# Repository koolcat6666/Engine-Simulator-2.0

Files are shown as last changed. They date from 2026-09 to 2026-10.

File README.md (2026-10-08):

# Engine Simulator 2.0

Engine simulator for ECU testing based on the Speeduino V0.4 and the ESP32-32U DevKitC.

The system connects to the ECU through the standard Speeduino 40-pin IDC connector and generates signals to simulate real engine operation.

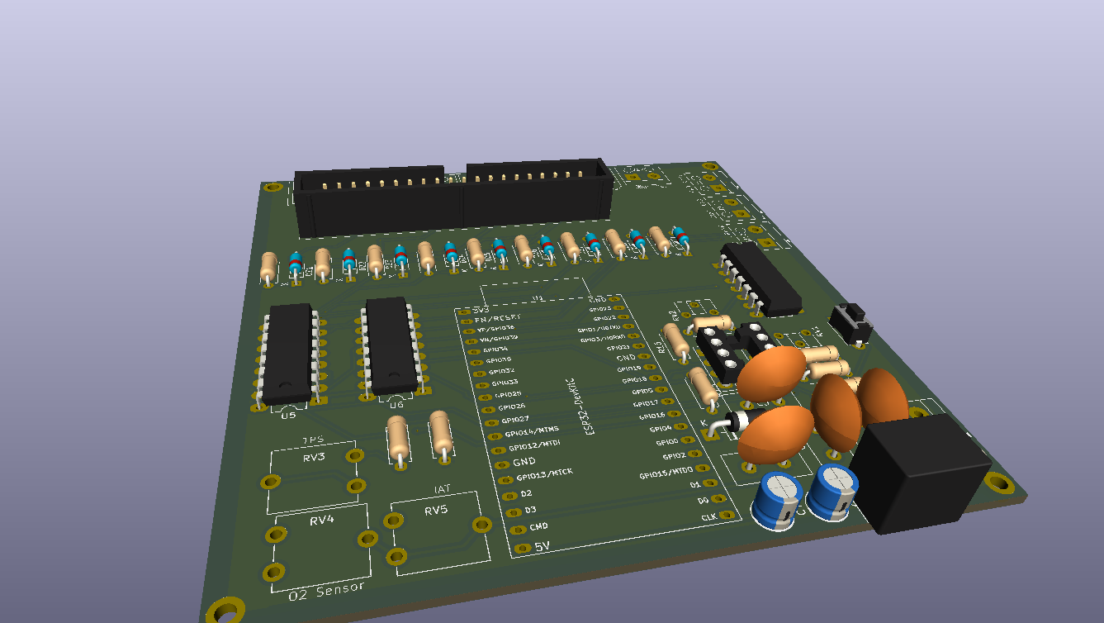
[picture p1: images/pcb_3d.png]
PCB 3D render


## Architecture

### Signals generated by the ESP32

| Signal | ESP32 Pin | To Speeduino | Method |
|:---|:---:|:---:|:---|
| Crank Trigger | GPIO 12 | IDC Pin 25 | Square wave via hardware timer and 3.3V-to-5V level shifter |
| Cam 1 Trigger | GPIO 13 | IDC Pin 24 | Square wave via hardware timer and 3.3V-to-5V level shifter |
| Cam 2 Trigger | GPIO 14 | IDC Pin 24 (optional) | Square wave via hardware timer and 3.3V-to-5V level shifter |
| CLT (Coolant Temperature) | GPIO 26 (DAC2) | IDC Pin 19 | Analog voltage 0–3.3V, amplified to 0–5V |
| MAP (Pressure) | GPIO 25 (DAC1) | IDC Pin 11 | Analog voltage 0–3.3V, amplified to 0–5V |

### Manually controlled signals (potentiometers)

| Signal | Speeduino Pin | Notes |
|:---|:---:|:---|
| TPS (Throttle Position Sensor) | IDC Pin 22 | 5V potentiometer, wiper/common connected to ESP32 ADC (GPIO 34) through a voltage divider |
| IAT (Intake Air Temperature) | IDC Pin 20 | Potentiometer connected directly to Speeduino |
| O2 (Oxygen Sensor) | IDC Pin 21 | Potentiometer connected directly to Speeduino |

### ECU input signals

| Signal | ESP32 Pin | From Speeduino | Notes |
|:---|:---:|:---:|:---|
| Fan Feedback | GPIO 27 | IDC Pin 15 | Fan status (0V = ON), 5V-to-3.3V voltage divider |

### ECU outputs monitoring

Speeduino outputs such as injectors, ignition/coils, fan, idle, VVT, boost, and fuel pump are read by the ESP32 through CD4050BE buffers for timing calculation (Phase 2).

---

## Firmware features

- 64 trigger wheel / crank patterns (ArduStim compatible): 60-2, 36-1, 24-1, LS1, 58X, Chrysler NGC, BMW N20, GM 40-tooth OSS, and many others
- RPM inertia model: cranking from 0 to 350 RPM, then idle at 850 RPM + (TPS × 6150), with low-pass filtering
- Start/Stop button: starts and stops the engine with a cranking ramp, idle stabilization, and gradual shutdown
- Dynamic MAP simulation: 100 kPa with engine off, 85 kPa during cranking, and 30–100 kPa depending on RPM and TPS
- Dynamic CLT simulation: gradual warm-up, fan cooling, and Newton cooling when engine is off
- USB serial interface: ArduStim protocol for configuring trigger wheel and crank pattern, as well as RPM mode from TunerStudio
- Speeduino timing monitoring (Phase 2): input capture via ISR on 9 CD4050BE inputs (4 injectors + 4 coils + fan), measuring injector on-time, pulse frequency, duty cycle, ignition dwell and advance
- WiFi AP + web dashboard (Phase 3): SSID `EngineSimulator2.0`, password `1234567890`, IP `192.168.254.1`, responsive dashboard at `/`, allows selecting one of 64 trigger patterns and persists the setting to NVS memory

### Verification status

| Module | Status |
|:---|:---|
| Phase 1 — Crank/Cam generation and engine model | Verified on hardware (Speeduino / Mega2560 reads engine speed correctly; fixed GPIO register usage `GPIO.out_w1ts/w1tc` in the ISR for core v3.3.x) |
| Phase 2 — Injector/ignition timing (input capture) | Implemented and compiled successfully — hardware validation pending |
| Phase 3 — WiFi AP + web dashboard | Implemented and compiled successfully — hardware validation pending |

Details and references: `firmware/WORKING_VERSION.md`.

---

## Directory structure

```
Engine Simulator 2.0/
||| firmware/                    # ESP32 source code
|   ||| Engine_Simulator_2.0.ino # Main sketch (timer, simulation, state machine)
|   ||| comms.cpp                # Serial command parser (ArduStim protocol)
|   ||| comms.h                  # Comms header
|   ||| globals.h                # Shared data structures
|   ||| timing.cpp               # Input capture timing for injectors/ignition (Phase 2)
|   ||| timing.h                 # Timing header
|   ||| web.cpp                  # WiFi AP + dashboard + /setup + /api/data (Phase 3)
|   ||| web.h                    # Web header
|   ||| wheel_defs.h             # 63 trigger wheel definitions
||| Engine_Simulator_2_0/        # Arduino IDE copy (folder name matches .ino project)
||| Hardware/                    # PCB design (KiCad 10.0)
|   ||| Engine Simulator 2.0/
|       ||| *.kicad_sch          # Schematic
|       ||| *.kicad_pcb          # PCB layout
|       ||| *.kicad_pro          # KiCad project
|       ||| BOM.md               # Bill of materials (updated from netlist)
|       ||| Gerbers/             # Manufacturing files (Gerber + drill)
||| doc/                         # Documentation
|   ||| dupont_pinout.md         # Speeduino V0.4 40-pin IDC pinout
|   ||| esp32u_pin_assignment.md # ESP32U pin mapping
||| README.md                    # This file
```

---

## Hardware requirements

### Main components

| Component | Quantity | Description |
|:---|:---:|:---|
| ESP32-WROOM-32U | 1 | Main microcontroller |
| 74AHCT125 | 1 | Quadruple level shifter 3.3V -> 5V (Crank, Cam1, Cam2) |
| TLV2372 | 1 | Dual rail-to-rail op-amp (MAP/CLT buffers) |
| R-78E5.0-1.0 (RECOM) | 1 | Switching regulator drop-in 12V -> 5V, 1A, 91% efficiency |
| 40-pin IDC connector | 1 | Connection to Speeduino V0.4 |
| CD4050BE | 2 | Hex buffer for ECU inputs (injectors, ignition, fan) |
| Trimmer potentiometers | 5 | (2 kΩ x2, 10 kΩ x3) — TPS, IAT, O2, and others |
| Push button | 1 | Start/Stop |
| DC barrel jack | 1 | 12V power input |

### Voltage levels

| Section | Voltage | Method |
|:---|:---:|:---|
| Board power supply | 12V | External DC barrel jack |
| Logic supply | 5V | R-78E5.0-1.0 switching regulator from 12V |
| ESP32 and sensors | 3.3V | Onboard regulator |
| ESP32 digital outputs -> ECU | 3.3V -> 5V | 74AHCT125 |
| ESP32 analog outputs -> ECU | 0–3.3V -> 0–5V | TLV2372 (gain 1.5x) |
| Fan input from ECU | 5V -> 3.3V | Resistive divider |

---

## Build and upload

### Prerequisites

- [Arduino IDE](https://www.arduino.cc/en/software) or [Arduino CLI](https://arduino.github.io/arduino-cli/)
- ESP32 board package installed: `esp32:esp32` via Board Manager
- Selected board: `ESP32 Dev Module` or `ESP32-WROOM-32U`
- Libraries for the dashboard (Phase 3): use **ESP32Async** (compatible with ESP32 core v3.3.x and mbedTLS 3; the classic `me-no-dev` version does not compile)
  - **ESP Async WebServer** (`arduino-cli lib install "ESP Async WebServer"`)
  - **Async TCP** (`arduino-cli lib install "Async TCP"`)

### Compile and upload

```bash
# Via Arduino CLI (first time: install the dashboard libraries as well)
arduino-cli lib install "ESP Async WebServer" "Async TCP"
arduino-cli compile --fqbn esp32:esp32:esp32 firmware/Engine_Simulator_2.0.ino
arduino-cli upload --fqbn esp32:esp32:esp32 --port COMx firmware/Engine_Simulator_2.0.ino
```

### Configuration

The trigger wheel/crank pattern can be selected in the following ways:

1. Dashboard web interface (recommended): connect to WiFi `EngineSimulator2.0` (password `1234567890`) and open `http://192.168.254.1` -> page `/setup` to select the pattern (persisted to NVS memory)
2. USB serial (115200 baud): use command `X` to select the next pattern, or `S<n>` to select by index
3. ArduStim GUI: desktop software connecting via serial to configure patterns and modes

---

## Project notes

- The integrated MAP sensor on the Speeduino V0.4 (IDC Pin 11) cannot be used as an alternative to the DAC-generated signal from the ESP32 for simulation. In this case, the MAP pin of the IDC must be disconnected and re-routed to the proper simulation output.
- The fan is managed with feedback: Speeduino controls it, and the ESP32 reads it to model CLT temperature.
- The IAT and O2 potentiometers are purely manual and do not affect the ESP32 simulation. They are used to test ECU corrections.
- The KiCad PCB (`Hardware/Engine Simulator 2.0/`) is complete: 2-layer routing with a solid GND plane on the bottom copper layer and thermal reliefs. DRC: no clearance errors and no unconnected pads; only cosmetic warnings remain.
- The design is intended to be a compact, low-cost and fully functional engine simulation interface for ECU testing and development.

### Manufacturing outputs (Gerber + drill)

Manufacturing files are generated with `kicad-cli` and are ready for any fabrication house (JLCPCB, PCBWay, PCBcart):

- `Hardware/Engine Simulator 2.0/Gerbers/` — Gerber RS-274X, 9 layers (`F_Cu`, `B_Cu`, `F_Paste`, `B_Paste`, `F_Mask`, `B_Mask`, `F_SilkS`, `B_SilkS`, `Edge_Cuts`) + `.gbrjob` file
- `Hardware/Engine Simulator 2.0/Gerbers/` — Separate Excellon drill files: `-PTH.drl` (plated holes, 0.3–2.2 mm) and `-NPTH.drl` (non-plated holes)
- `Hardware/Engine Simulator 2.0/Engine_Simulator_2.0_FAB_gerbers.zip` — ZIP archive containing all Gerber and drill files, ready for direct upload to the manufacturer

Board: 2 layers, 100 × 100 mm, thickness 1.6 mm, HASL finish, minimum trace width 0.2 mm, minimum clearance 0.21 mm, minimum drill 0.3 mm (via) / 2.2 mm (M2 mounting holes, PTH connected to GND).

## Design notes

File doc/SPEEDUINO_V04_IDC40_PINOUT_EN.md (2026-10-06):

# Speeduino V0.4 - IDC 40-Pin Connector Pinout

Pinout ufficiale del connettore IDC 40 pin della **Speeduino V0.4**.  
Riferimento: [Speeduino Wiki - V04 Board](https://wiki.speeduino.com/en/boards/V04)

## IDC 40-Pin Pinout Table (Speeduino V0.4)

| Pin IDC | Funzione |
|:---:|:---|
| 1 | Injector 1 - Pin 1/2 |
| 2 | Injector 2 - Pin 1/2 |
| 3 | Injector 3 - Pin 1/2 |
| 4 | Injector 3 - Pin 2/2 |
| 5 | Injector 4 - Pin 1/2 |
| 6 | Injector 4 - Pin 2/2 |
| 7 | Ignition 1 |
| 8 | Ignition 4 |
| 9 | Ground (Sensori) |
| 10 | Ground |
| 11 | MAP Sensor (0-5V) |
| 12 | Ground |
| 13 | +5V |
| 14 | Proto Area 1 (v0.4.4b+: Flex Sensor) |
| 15 | Proto Area 2 (v0.4.4b+: Fan) |
| 16 | Proto Area 3 (v0.4.4b+: Fuel Pump) |
| 17 | Proto Area 4 (v0.4.4b+: Tachometer) |
| 18 | Proto Area 5 (v0.4.4b+: Clutch) |
| 19 | CLT (Coolant Temperature) |
| 20 | IAT (Inlet Air Temperature) |
| 21 | O2 Sensor |
| 22 | TPS (Throttle Position Sensor) |
| 23 | Ground |
| 24 | Cam Input / VR2+ |
| 25 | Crank Input / VR1+ |
| 26 | VR2- (non usato per sensori Hall) |
| 27 | VR1- (non usato per sensori Hall) |
| 28 | +5V |
| 29 | Stepper Motor 2B |
| 30 | Stepper Motor 2A |
| 31 | Stepper Motor 1A |
| 32 | Stepper Motor 1B |
| 33 | Ignition 3 |
| 34 | Ignition 2 |
| 35 | Boost Control |
| 36 | Idle 2 (3-wire idle valve) |
| 37 | PWM Idle (1-wire idle) |
| 38 | VVT |
| 39 | Injector 2 - Pin 2/2 |
| 40 | Injector 1 - Pin 2/2 |

---

## Default Output Functions (v0.4.4b+)

| Funzione | Pin IDC | Arduino Pin | Note |
|:---|:---:|:---:|:-----|
| Boost Control | 35 | 7 | Disabilitare in TunerStudio e rimappare a Pin 4 |
| VVT | 38 | 4 | Disabilitare in TunerStudio |
| Idle 1 (PWM) | 37 | 5 | |
| Idle 2 (3-wire) | 36 | 6 | |
| Fuel Pump | 16 | 45 | Jumper da proto area |
| Fan | 15 | 47 | Jumper da proto area |
| Tachometer | 17 | 49 | Jumper da proto area |
| Launch/Clutch | 18 | 51 | Jumper da proto area |

---

## Sensori di Input (Pezzo 0.4)

| Funzione | Arduino Pin | Descrizione |
|:---|:---:|:---|
| Crank Trigger | 19 | Sensore CKP (VR o Hall) |
| Cam Trigger | 18 | Sensore CMP (VR o Hall) |
| Cam 2 / VVT2 | 3 | Secondo sensore fase |
| TPS | A2 | Throttle Position Sensor |
| MAP | A3 | MAP Sensor (integrato sulla board) |
| IAT | A0 | Intake Air Temperature |
| CLT | A1 | Coolant Temperature |
| O2 | A8 | Sonda Lambda |
| Battery | A4 | Riferimento tensione batteria |

---

## Collegamenti verso Engine Simulator 2.0 (ESP32)

Di seguito la mappatura dei pin IDC collegati all'ESP32 sul PCB del simulatore:

| Pin IDC | Funzione Speeduino | Direzione (per ECU) | Collegamento ESP32 | Note Hardware |
|:---:|:---:|:---:|:---:|:---|
| 11 | MAP | **Ingresso ECU** | DAC1 (GPIO 25) via op-amp | Generato da ESP32 (0-3.3V amplificato a 0-5V) |
| 19 | CLT | **Ingresso ECU** | DAC2 (GPIO 26) via op-amp | Generato da ESP32 (0-3.3V amplificato a 0-5V) |
| 20 | IAT | **Ingresso ECU** | Potenziometro manuale | Regolatore esterno, collegato direttamente a Speeduino |
| 22 | TPS | **Ingresso ECU** | Potenziometro con partitore | Regolatore esterno, collegato a Speeduino + partitore verso ESP32 ADC (GPIO 34) |
| 21 | O2 | **Ingresso ECU** | Potenziometro manuale | Regolatore esterno, collegato direttamente a Speeduino |
| 25 | Crank | **Uscita ECU** (input per Speeduino) | GPIO 12 via level shifter 3.3V->5V | Segnale generato da ESP32 |
| 24 | Cam | **Uscita ECU** (input per Speeduino) | GPIO 13 via level shifter 3.3V->5V | Segnale generato da ESP32 |
| 15 | Fan | **Uscita ECU** | CD4050-A out 6 -> GPIO 27 | Lettura stato ventola (temperatura CLT) |
| 1 | Injector 1 | **Uscita ECU** | CD4050-B out 4 -> GPIO 15 | Input capture timing (FASE 2) |
| 2 | Injector 2 | **Uscita ECU** | CD4050-B out 6 -> GPIO 16 | Input capture timing (FASE 2) |
| 3 | Injector 3 | **Uscita ECU** | CD4050-B out 10 -> GPIO 17 | Input capture timing (FASE 2) |
| 5 | Injector 4 | **Uscita ECU** | CD4050-B out 12 -> GPIO 18 | Input capture timing (FASE 2) |
| 7 | Ignition 1 | **Uscita ECU** | CD4050-A out 10 -> GPIO 19 | Input capture timing (FASE 2) |
| 8 | Ignition 4 | **Uscita ECU** | CD4050-A out 2 -> GPIO 23 | Input capture timing (FASE 2) |
| 33 | Ignition 3 | **Uscita ECU** | CD4050-A out 15 -> GPIO 22 | Input capture timing (FASE 2) |
| 34 | Ignition 2 | **Uscita ECU** | CD4050-A out 12 -> GPIO 21 | Input capture timing (FASE 2) |
| 37 | Idle (PWM) | **Uscita ECU** | Non monitorata | (Monitorabile in futuro) |
| 35 | Boost | **Uscita ECU** | Non monitorata | (Monitorabile in futuro) |
| 38 | VVT | **Uscita ECU** | Non monitorata | (Monitorabile in futuro) |
| 16 | Fuel Pump | **Uscita ECU** | Non monitorata | (Monitorabile in futuro) |

---

## Note sui Livelli di Tensione

### Uscite ESP32 -> Speeduino (3.3V -> 5V)
I segnali digitali generati dall'ESP32 (Crank, Cam1) sono a logica 3.3V. Devono essere traslati a 5V tramite **74AHCT125** (level shifter) prima di essere inviati ai pin Crank/Cam dell'IDC.

### Uscite Analogiche ESP32 -> Speeduino
I DAC dell'ESP32 (GPIO 25, 26) erogano 0-3.3V. Vanno amplificati a 0-5V tramite **op-amp rail-to-rail** (TLV2372) con guadagno ~1.5x per compatibilita' con gli ingressi analogici di Speeduino (MAP e CLT).

### Ingressi da Speeduino -> ESP32 (5V -> 3.3V)
Il segnale Fan (pin 15 IDC) e' a 5V. Deve essere ridotto a 3.3V tramite partitore resistivo prima di essere letto dal GPIO 27 dell'ESP32.

### Potenziometri TPS/IAT/O2
I potenziometri sono alimentati a 5V (condiviso con Speeduino). Il cursore va collegato:
- **TPS**: a Speeduino (pin 22 IDC) + partitore resistivo 10k/20k verso GPIO 34 ESP32
- **IAT**: direttamente a Speeduino (pin 20 IDC), nessun collegamento ESP32
- **O2**: direttamente a Speeduino (pin 21 IDC), nessun collegamento ESP32

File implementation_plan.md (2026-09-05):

# Engine Simulator 2.0 - Implementation Plan

Il progetto **Engine Simulator 2.0** ha lo scopo di creare un simulatore ECU basato su ESP32, compatibile a livello seriale con ArduStim, ma arricchito con la simulazione fisica dei parametri motore (MAP, CLT, inerzia RPM basata su TPS, sequenza di cranking con pulsante di Start/Stop) e un'interfaccia hardware (PCB) per connettersi direttamente a Speeduino tramite un connettore Dupont a 40 pin.

---

## User Review Required

> [!IMPORTANT]
> **Compatibilità di Tensione e Level Shifting:**
> - ESP32 lavora a **3.3V** sia per gli ingressi analogici (ADC max 3.3V) che per i GPIO.
> - Speeduino lavora a **5V**.
> - I potenziometri (TPS, IAT, CLT, O2) saranno alimentati a 5V per Speeduino. Per far leggere il TPS anche a ESP32 senza bruciare l'ADC, si utilizzerà un partitore resistivo o un buffer sul PCB.
> - Le uscite dell'ESP32 (Crank, Cam, Cam2) devono passare attraverso un level shifter a 5V prima di raggiungere Speeduino.
> - Gli ingressi di Speeduino letti da ESP32 (es. comando Ventola di raffreddamento a 5V) passeranno attraverso un level shifter a 3.3V.

> [!TIP]
> **Generazione Analogica (CLT e MAP):**
> L'ESP32 ha 2 canali DAC integrati a 8 bit (GPIO25 e GPIO26). Li useremo per generare le tensioni analogiche di MAP e CLT (che andranno poi traslate a 0-5V tramite op-amp sul PCB se Speeduino richiede range 0-5V, dato che i DAC di ESP32 erogano 0-3.3V).

---

## Proposed Changes

Creeremo la cartella `C:\Users\nicola\Desktop\Engine Simulator 2.0` con la seguente struttura di file:

### Componente 1: Firmware ESP32
Adatteremo la logica di generazione delle ruote foniche di ArduStim per usare i timer hardware di ESP32 (tramite le API ESP32 Arduino Core `esp32-hal-timer.h`), implementando al contempo le routine di simulazione fisica in background.

#### [NEW] [Engine_Simulator_2.0.ino](file:///C:/Users/nicola/Desktop/Engine%20Simulator%202.0/firmware/Engine_Simulator_2.0.ino)
Contiene il punto di ingresso dell'applicazione, la configurazione dei timer hardware di ESP32 per la ruota fonica e il loop principale che gestisce:
- Lettura pulsante Start/Stop (con debouncing e macchina a stati del motore: `SPENTO`, `CRAKING`, `ACCESO`, `SPEGNIMENTO`).
- Lettura TPS (ADC ESP32) e calcolo dinamico degli RPM correnti applicando le leggi di inerzia (accelerazione e decelerazione simulate).
- Calcolo e aggiornamento dell'uscita DAC per **MAP** (in base a RPM, TPS, tasso di variazione RPM).
- Calcolo e aggiornamento dell'uscita DAC per **CLT** (in base a tempo di accensione, RPM, stato della ventola letto dall'ECU).
- Gestione della comunicazione seriale (comandi ArduStim per cambiare ruota fonica o ricevere configurazioni).

> **[!IMPORTANT] Fix verificato su hardware (2026-09):** sulla ISR del timer `onCrankTimer()` l'uso di `digitalWrite()` NON aggiorna i pin GPIO su ESP32 Arduino Core v3.3.5 (i segnali Crank/Cam restavano a 0V anche a motore avviato). Risolto sostituendo `digitalWrite` con la **scrittura diretta ai registri GPIO** (`GPIO.out_w1ts` per HIGH, `GPIO.out_w1tc` per LOW), che funziona sempre dentro una ISR. Aggiunti gli include `soc/gpio_struct.h` e `soc/gpio_reg.h`. Dopo questa patch il segnale Crank/Cam commuta correttamente (tensione media ~1.6V = square 3.3V a duty ~50%) e Speeduino/Mega2560 legge i giri.

#### [NEW] [wheel_defs.h](file:///C:/Users/nicola/Desktop/Engine%20Simulator%202.0/firmware/wheel_defs.h)
Le definizioni delle ruote foniche importate da ArduStim (es. 60-2, 36-1, ecc.) adattate per ESP32.

#### [NEW] [comms.h](file:///C:/Users/nicola/Desktop/Engine%20Simulator%202.0/firmware/comms.h) & [comms.cpp](file:///C:/Users/nicola/Desktop/Engine%20Simulator%202.0/firmware/comms.cpp)
Modulo di comunicazione seriale compatibile con l'interfaccia ArduStim per consentire la selezione del pattern e configurazioni tramite PC.

---

### Componente 2: Documentazione Hardware & Repository
#### [NEW] [README.md](file:///C:/Users/nicola/Desktop/Engine%20Simulator%202.0/README.md)
Documentazione completa per GitHub, contenente:
- Descrizione del progetto.
- Schema a blocchi dell'hardware (Alimentazione 12V -> Regolatori 5V e 3.3V, Level Shifter, DAC 0-3.3V amplificati a 0-5V per MAP e CLT).
- Pinout del connettore Dupont a 40 pin per l'interfaccia con Speeduino.
- Guida all'uso e alla calibrazione.

#### [NEW] [dupont_pinout.md](file:///C:/Users/nicola/Desktop/Engine%20Simulator%202.0/doc/dupont_pinout.md)
Tabella dettagliata delle connessioni tra ESP32, Level Shifter e connettore Dupont a 40 pin di Speeduino.

---

## Logiche Fisiche Simulate

### 1. Inerzia RPM da TPS
- Quando il motore è acceso, il regime target è proporzionale all'apertura del TPS.
- Gli RPM effettivi seguono il target con un ritardo controllato da un coefficiente di inerzia (simulando la massa del volano):
  $$\text{RPM}_{\text{curr}} = \text{RPM}_{\text{curr}} + (\text{RPM}_{\text{target}} - \text{RPM}_{\text{curr}}) \times K_{\text{inerzia}}$$

### 2. Pressione Collettore (MAP)
- A motore spento: MAP = Pressione Atmosferica (~4.0V - 4.5V sul sensore a seconda del sensore MAP simulato).
- In Idle (TPS basso, RPM stabili): MAP cala drasticamente (forte vuoto, ~1.0V - 1.5V).
- In Accelerazione (TPS alto, RPM in salita): MAP sale rapidamente verso la pressione atmosferica (~4.0V) prima che gli RPM aumentino del tutto.
- In Decelerazione (TPS chiuso, RPM alti): MAP scende al minimo storico (~0.5V - 0.8V).

### 3. Temperatura Refrigerante (CLT)
- A motore spento da tempo: CLT = Temperatura Ambiente.
- A motore acceso: CLT sale gradualmente verso una temperatura di esercizio (~90°C). La velocità di riscaldamento dipende dagli RPM.
- Se CLT supera la soglia della ventola (~95°C), Speeduino attiva l'uscita Ventola. L'ESP32 rileva questo input e aumenta il coefficiente di raffreddamento, facendo calare o stabilizzare la temperatura.
- A motore spento: CLT scende lentamente verso la temperatura ambiente seguendo la legge del raffreddamento di Newton.

---

## FASE 2 - Level Shifter Ingressi + Monitoraggio Timing Iniettori/Candele

> [!NOTE]
> Questa sezione descrive l'implementazione pianificata. **Il monitoraggio PWM di iniettori/candele NON è ancora implementato** nel codice (gli 8-9 ingressi non sono ancora gestiti). Il firmware base (generazione Crank/Cam + modello motore) è invece funzionante e verificato su Speeduino.

### Obiettivo

Monitorare i segnali **PWM di uscita della Speeduino** (4 iniettori + 4 candele + ventola) per misurare i **tempi di apertura iniettori (ms) e l'anticipo candela (°)**. Questo consente di verificare in tempo reale che la ECU e le correzioni (lambda, CLT, ecc.) effettivamente modifichino i parametri.

### 1. Corsia dati: i segnali Speeduino da leggere (IDC 40 pin V0.4)

| # | Segnale | Pin IDC | Natura |
|:-:|:---|:---:|:---|
| 1 | Injector 1 | 1 | PWM low-side, attivo basso |
| 2 | Injector 2 | 2 | PWM low-side, attivo basso |
| 3 | Injector 3 | 3 | PWM low-side, attivo basso |
| 4 | Injector 4 | 5 | PWM low-side, attivo basso |
| 5 | Ignition 1 | 7 | PWM low-side, attivo basso |
| 6 | Ignition 2 | 34 | PWM low-side, attivo basso |
| 7 | Ignition 3 | 33 | PWM low-side, attivo basso |
| 8 | Ignition 4 | 8 | PWM low-side, attivo basso |
| 9 | Fan (retroazione ECU) | — | Segnale comando ventola, letto via CD4050-A |

Questi segnali sono a **5V/12V logica Speeduino**. Per leggerli con l'ESP32 (3.3V) serve una **rete di protezione + buffer** (CD4050BE) su ciascun ingresso.

### 2. Level Shifter: componente e necessita'

**Motivo:** Gli output iniettori/candele di Speeduino sono **low-side**: il pin IDC oscilla tra ~0V (ON) e fino a **12V** (batteria/Vdrive) quando OFF. Leggere direttamente questo pin supera i 3.3V dell'ESP32 e danneggerebbe sia il GPIO che qualsiasi level shifter a 5V (Vmax ~5.5V). Gli ESP32 DevKitC **non sono 5V/12V tolerant** → serve protezione dedicata.

**Componente scelto: 2x CD4050BE** (Hex Non-Inverting Buffer, 6 canali l'uno).

| Proprieta' | Valore |
|:---|:---|
| Tolleranza ingresso | **VDD max 18V** → sopporta i 12V Speeduino senza danno |
| Canali | 6 per chip (ne servono 8 ⇒ **2 chip**) |
| Alimentazione (decisione) | **VDD = 3.3V**, GND condiviso con ESP32 |
| Uscita | Livello VDD = **3.3V**, già compatibile direttamente con GPIO ESP32 |
| Direzione | Unidirezionale (ingresso → uscita), perfetto per la lettura |

**Cablaggio (2 chip CD4050BE, 1 chip per sistema):**

```
Speeduino IDC (iniettori/candele/ventola, 0-12V)
        |   (ogni segnale su un ingresso)
        ▼
  [ CD4050BE-A  = IGNITION  (4 candele: IGN1-4 + FAN) ]
  [ CD4050BE-B  = INJECTION (4 iniettori: INJ1-4)      ]
        |  (VDD=3.3V, GND=GND ESP32)
        ▼
  GPIO ESP32 (9 ingressi, livello 3.3V)
```

> Distribuzione finale verificata: **CD4050BE-A = IGNITION** (buffer 9→10, 11→12, 14→15, 3→2 + FAN 7→6), **CD4050BE-B = INJECTION** (buffer 5→4, 7→6, 9→10, 11→12). Vedi sezioni 2.3-2.4 per i dettagli pin per pin.

> La VDD a 3.3V fa sì che l'uscita dei CD4050 sia già a livello logico compatibile con l'ESP32, eliminando ulteriori partitori sul cammino dei segnali di monitoraggio.

#### 2.1 Rete di protezione ingresso (per ciascuno degli 8 canali)

Prima dell'ingresso del CD4050 si inserisce una rete di protezione che limita la corrente e **clampa la tensione** sotto la soglia logica. Il CD4050 in sè regge 12V, ma la rete protegge da errori di cablaggio/spike e mantiene l'ingresso a livello pulito.

**Schema per canale (TH - Through Hole):**

```
Speeduino IDC ──[R 2.2k 1/4W]──┬──────> CD4050 IN
 (iniettore/candela)           │
                          Zener 3.6V
                          (BZX55C3V6, DO-35)
                               │
                              GND
```

| Componente | Valore | Package TH | Ruolo |
|:---|:---|:---|:---|
| R serie | **2.2kΩ** 1/4W | TH | Limita corrente verso lo Zener e l'ingresso CD4050 |
| Zener | **3.6V** (`BZX55C3V6`) | **DO-35 (TH)** | Clampa la sovratensione appena sopra 3.3V, protegge ingresso e GPIO |

**Nota sulla disponibilità (TH):** il **BZX55C3V6** è in contenitore **DO-35 (TH**, 2 pin, 0.5W) — facile da trovare. Valori TH equivalenti se il 3.6V non fosse disponibile:

| Alternativa | Tensione | Package TH |
|:---|:---:|:---|
| 1N5226B | 3.3V | DO-35 |
| BZX55C3V6 | 3.6V | DO-35 (scelto) |
| 1N5228B | 3.9V | DO-35 |

> Lo **Zener 3.6V** (e non 5.1V) è stato scelto perché clampando appena sopra i 3.3V protegge davvero l'ingresso, dato che il CD4050 è alimentato a VDD=3.3V. Un clamp a 5.1V sarebbe ridondante/parziale. I diodi Schottky (BAT85/1N5819) non sono Zener e non fanno clamp di soglia: scartati.

**Quantità rete protezione:** 9 canali ⇒ 9× R2.2k + 9× BZX55C3V6 (tutti TH).

#### 2.2 Simbolo KiCad per il CD4050BE

> Il CD4050B **non è presente** nelle librerie standard di KiCad 10 (il simbolo "Hex Buffer" generico esistente ha una pinout diversa e va scartato). La libreria Digi-Key esiste ma usa il formato `.lib` legacy, poco compatibile con KiCad 9/10 per un singolo componente.

**Soluzione consigliata: creare un simbolo custom** in una libreria di progetto (`.kicad_sym`) con la pinout confermata da datasheet TI (CD4049UB/CD4050B).

**Pinout CD4050BE (PDIP-16, da datasheet TI):**

| Pin | Funzione | Pin | Funzione |
|:---:|:---|:---:|:---|
| 1 | VDD | 16 | **NC** (non connesso) |
| 2 | OUT (G) | 15 | OUT (L) |
| 3 | IN (A) | 14 | IN (F) |
| 4 | OUT (H) | 13 | **NC** (non connesso) |
| 5 | IN (B) | 12 | OUT (K) |
| 6 | OUT (I) | 11 | IN (E) |
| 7 | IN (C) | 10 | OUT (J) |
| 8 | VSS (GND) | 9 | IN (D) |

> **Importante (dal datasheet TI, SCHS046):** i pin **13 e 16 sono NC** (non connessi internamente).  
> I **6 buffer validi** sono sulle coppie (IN→OUT): **(3→2), (5→4), (7→6), (9→10), (11→12), (14→15)**.  
> Ingressi: A=3, B=5, C=7, D=9, E=11, F=14 · Uscite: G=2, H=4, I=6, J=10, K=12, L=15.  
> **NON usare i pin 13 e 16 come ingresso/uscita.**

**Dati chiave CD4050B (da datasheet):**
- Buffer **non-inverting**, **6 canali** (hex)
- **Pin 13 e 16 = NC** — usare solo le 6 coppie valide sopra
- VDD range **3–18V** (sopporta i 12V)
- Corrente ingresso max 1µA, TH tollerante
- Package TH: **PDIP-16** → footprint `Package_DIP:DIP-16_W7.62mm`

**Procedura in KiCad:**
1. `File → New → Symbol Library` → crea `engine_sim.kicad_sym` nella cartella progetto
2. `File → New Symbol` → nome `CD4050BE`
3. Aggiungi i pin secondo la tabella sopra (6 coppie valide + VDD pin1 + VSS pin8; pin 13/16 NC)
4. Assegna footprint `Package_DIP:DIP-16_W7.62mm`
5. Salva

**Footprint di riferimento (per CD4050BE TH):** `Package_DIP:DIP-16_W7.62mm`

### 2.3 Assegnazione dei 2 chip (CD4050BE-A e CD4050BE-B)

I 2 chip CD4050BE sono divisi **per sistema**: **chip A = Ignition (4 candele)**, **chip B = Injection (4 iniettori)**. Ogni chip usa solo le coppie valide (le 6 di datasheet TI); i pin 13 e 16 NC non vengono mai usati. Entrambi i chip: **VDD(pin1)=3.3V**, **VSS(pin8)=GND**.

**CD4050BE-A (IGNITION + FAN — 4 candele + ventola):**

| Segnale | Pin IDC | IN CD4050-A | OUT CD4050-A | GPIO ESP32 | PIN DevKitC |
|:---|:---:|:---:|:---:|:---:|:---:|
| IGN1 | 7 | 9 | 10 | GPIO 19 | 31 |
| IGN2 | 34 | 11 | 12 | GPIO 21 | 33 |
| IGN3 | 33 | 14 | 15 | GPIO 22 | 36 |
| IGN4 | 8 | 3 | 2 | GPIO 23 | 37 |
| FAN | — | 7 | 6 | GPIO 27 | 11 |

**CD4050BE-B (INJECTION — 4 iniettori):**

| Iniettore | Pin IDC | IN CD4050-B | OUT CD4050-B | GPIO ESP32 | PIN DevKitC |
|:---|:---:|:---:|:---:|:---:|:---:|
| INJ1 | 1 | 5 | 4 | GPIO 15 | 23 |
| INJ2 | 2 | 7 | 6 | GPIO 16 | 27 |
| INJ3 | 3 | 9 | 10 | GPIO 17 | 28 |
| INJ4 | 5 | 11 | 12 | GPIO 18 | 30 |

> Ogni ingresso (IN) viaggia attraverso la **rete di protezione** (R 2.2k + Zener 3.6V). Il **chip A** usa 5 dei 6 buffer valevi (4 candele + Fan), il **chip B** ne usa 4. Pin 13 e 16 NC su entrambi, mai usati; i buffer liberi restano scollegati.

#### 2.4 Tabella di connessione per sistema (Ignition / Injection)

Vista consolidata organizzata per **sistema** — **1 chip per sistema** (tutti i valori in pin fisici CD4050 da datasheet TI):

**CD4050BE-A = IGNITION + FAN (4 candele + ventola):**

| Segnale | Pin IDC | IN CD4050-A | OUT CD4050-A | GPIO ESP32 | PIN DevKitC |
|:---|:---:|:---:|:---:|:---:|:---:|
| IGN1 | 7 | 9 | 10 | GPIO 19 | 31 |
| IGN2 | 34 | 11 | 12 | GPIO 21 | 33 |
| IGN3 | 33 | 14 | 15 | GPIO 22 | 36 |
| IGN4 | 8 | 3 | 2 | GPIO 23 | 37 |
| FAN | — | 7 | 6 | GPIO 27 | 11 |

**CD4050BE-B = INJECTION (4 iniettori):**

| Iniettore | Pin IDC | IN CD4050-B | OUT CD4050-B | GPIO ESP32 | PIN DevKitC |
|:---|:---:|:---:|:---:|:---:|:---:|
| INJ1 | 1 | 5 | 4 | GPIO 15 | 23 |
| INJ2 | 2 | 7 | 6 | GPIO 16 | 27 |
| INJ3 | 3 | 9 | 10 | GPIO 17 | 28 |
| INJ4 | 5 | 11 | 12 | GPIO 18 | 30 |

> Il **chip A** usa 5 buffer (4 candele + Fan), il **chip B** ne usa 4. Pin 13 e 16 NC su entrambi, mai usati. VDD(pin1)=3.3V, VSS(pin8)=GND su entrambi.

### 3. Identificazione dei 9 ingressi ESP32 (GPIO)

Firmware attuale usa: GPIO 4, 34, 27, 25, 26, 12, 13, 14 (liberi tutti gli altri).  
Per il monitoraggio PWM servono GPIO **con interrupt/input capture** (tutti i GPIO supportano interrupt su ESP32). Scelta proposta (canale RTC libero, nessun conflitto con DAC/ADC usati):

| Funzione | GPIO | PIN DevKitC | Note |
|:---|:----:|:---:|:-----|
| Injector 1 | **GPIO 15** | PIN 23 | INPUT_PULLUP |
| Injector 2 | **GPIO 16** | PIN 27 | INPUT_PULLUP |
| Injector 3 | **GPIO 17** | PIN 28 | INPUT_PULLUP |
| Injector 4 | **GPIO 18** | PIN 30 | INPUT_PULLUP |
| Ignition 1 | **GPIO 19** | PIN 31 | INPUT_PULLUP |
| Ignition 2 | **GPIO 21** | PIN 33 | INPUT_PULLUP |
| Ignition 3 | **GPIO 22** | PIN 36 | INPUT_PULLUP |
| Ignition 4 | **GPIO 23** | PIN 37 | INPUT_PULLUP |
| Fan (via CD4050-A) | **GPIO 27** | PIN 11 | INPUT_PULLUP |

> Questi GPIO non confliggono con i pin di I/O già assegnati (TPS, MAP, CLT, Crank, Cam1, Cam2, Fan, Start/Stop) — il GPIO 27/Fan è un'uscita del CD4050-A (buffer 7→6) che rientra già tra i GPIO usati dal firmware.
>
> **Nota mappatura pin fisici DevKitC (verificata dalla scheda):** GPIO15→PIN23, GPIO16→PIN27, GPIO17→PIN28, GPIO18→PIN30, GPIO19→PIN31, GPIO21→PIN33, GPIO22→PIN36, GPIO23→PIN37, GPIO27→PIN11. I numeri PIN in tutte le tabelle fanno riferimento a questa mappatura (non alla piedinatura standard di altri DevKitC).

### 4. Algoritmo di timing da implementare

Si userà una tecnica **"input capture su ISR + timestamp via micros()"** per misurare i parametri di ciascun canale senza bloccare il loop principale (che deve restare a bassa latenza per il modello motore).

#### 4.1 Misura tempi iniettore (duty / on-time)
Per ciascun canale iniettore si rileva il fronte di **salita e discesa** del segnale e si calcola in ISR:
- `onTime_us[ch]` = durata dell'impulso ATTIVO (apertura iniettore) in microsecondi → convertito in ms.
- `period_us[ch]` = periodo completo del ciclo (tra due iniezioni consecutive).
- **Frequenza iniezione** = `1 / period` (raddoppia nel semi-sequenziale/batch).

Questo dà direttamente il **tempo di iniezione** (in ms) che la ECU sta applicando, e permette di vedere le correzioni (incremento a CLT freddo, arricchimento in accelerazione, ecc.).

#### 4.2 Misura anticipo candela (spark timing)
Per la candela occorre non solo il duty ma la **posizione temporale dell'impulso rispetto al riferimento Crank**. Poiché l'ESP32 genera la ruota fonica (ed è quindi il "master", conosce il giro motore), si può:
- Rilevare l'impulso di candela sul canale ignition.
- Confrontare il timestamp con l'ultimo fronte del **Crank** (già generato localmente).
- Calcolare l'angolo in gradi = `(Δt / periodo_giro) × 360°`.

**Risultato:** anticipo candela in **gradi BTDC**, che è il parametro chiave che la ECU modifica con MAP/RPM (advance table).

#### 4.3 Su quali core/priorita' eseguire
- Gli 8 interrupt di input capture girano sulla ISR (istante di trigger, solo `micros()` e store in struttura volatile). **Fase 1 (generazione Crank/Cam)** resta invariata sul timer.
- Il **calcolo** dei valori finali (ms, gradi, frequenze) avviene nel loop (priorita' bassa) e viene solo **esposto** in memoria condivisa.
- Il **WiFi/web server** (fase successiva) e il seriale leggono i valori calcolati → niente conflitto di timing.

#### 4.4 Strutture dati (da aggiungere a `globals.h`)
```cpp
struct injectorChannel {
  volatile uint32_t onTimeUs;   // durata apertura (us)
  volatile uint32_t periodUs;   // periodo ciclo (us)
  volatile uint32_t lastRise;   // timestamp fronte di salita (micros)
  volatile uint32_t lastFall;   // timestamp fronte di discesa (micros)
  bool active;                  // uscita attiva?
};

struct ignitionChannel {
  volatile uint32_t sparkTimeUs;   // durata impulso candela
  volatile uint16_t advanceDeg;    // anticipo in gradi BTDC
  bool active;
};

extern injectorChannel injectors[4];
extern ignitionChannel ignitions[4];
```

#### 4.5 Interrupt handler (esempio concettuale, NON ancora nel codice)
```cpp
void IRAM_ATTR injISR() {
  uint32_t now = micros();
  bool pinState = digitalRead(injPin);
  if (pinState == LOW) {            // attivo basso: fronte di discesa = apertura
    inj.onTimeUs = now - inj.lastRise;
    inj.periodUs = now - inj.lastRise + inj.lastPeriod...; // gestendo frazioni
    inj.lastRise = now;
  }
}
```

### 5. Stub / placeholder nel codice attuale (da non modificare ancora)
- Nessuna modifica al software finche' non si approva il piano e si definisce la sequenza di sviluppo.
- I nuovi file/simboli saranno introdotti in una tranche successiva senza rompere la compilazione attuale (che e' verificata).

### 6. Verifica pianificata (Fase 2)
1. **Oscilloscopio sui 3 level shifter**: verificare che i segnali 5V → 3.3V siano integri (niente undershoot).
2. **Comparazione tempi**: confrontare i ms di iniezione misurati dal firmware con quelli mostrati da TunerStudio.
3. **Verifica anticipo**: confrontare i gradi calcolati con la spark advance table di Speeduino.
4. **Stabilità**: garantire che gli 8 ISR non interferiscano con la generazione Crank/Cam (test a RPM alti).

---

## Verification Plan

### Automated/Unit Tests
Non essendoci un banco di prova hardware automatico integrato nel computer locale, simuleremo le letture analogiche e i comportamenti fisici tramite un modulo di simulazione software attivabile via console seriale.

### Manual Verification
1. **Analisi su Oscilloscopio o Analizzatore Logico:** Verifica della corretta generazione dei segnali di Crank e Cam su GPIO selezionati.
2. **Test Seriale:** Connessione tramite terminale seriale (es. Arduino Serial Monitor) a 115200 baud per validare l'invio dei comandi di ArduStim e verificare le risposte.
3. **Verifica dei DAC:** Lettura delle uscite analogiche di MAP e CLT in risposta a variazioni del TPS (simulato) o del pulsante di Start.
4. **[x] Test Crank/Cam su Speeduino (eseguito):** completo — il firmware genera Crank (GPIO12)/Cam1 (GPIO13)/Cam2 (GPIO14) a 3.3V e Speeduino (Mega2560) legge correttamente i giri. Richiedeva la fix ai registri GPIO nella ISR (vedi sezione Componente 1). Il pulsante Start/Stop (GPIO4) avvia il motore fino a ~850 rpm idle; sulle uscite Crank/Cam si misura ~1.6V di media (square 3.3V duty ~50%).

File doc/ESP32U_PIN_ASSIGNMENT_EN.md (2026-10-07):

# ESP32U Pin Assignment — Engine Simulator 2.0

## Overview

This document specifies the pin configuration for the **ESP32-WROOM-32U** microcontroller module used in the Engine Simulator 2.0 project.

The ESP32-WROOM-32U features a U.FL antenna connector for external RF antenna integration while maintaining the standard 38-pin form factor and pinout of the ESP32 WROOM family.

---

## Functional Responsibilities

The ESP32 module is responsible for:

- **Signal generation** — Produces digital trigger signals for crankshaft position (CKP), camshaft position bank 1 (CMP1), and camshaft position bank 2 (CMP2)
- **Analog simulation** — Generates MAP (manifold absolute pressure) and CLT (coolant temperature) sensor voltages
- **Input monitoring** — Reads throttle position sensor (TPS) for RPM target determination and fan feedback state
- **Control interface** — Manages engine start/stop button input

**Note:** IAT (intake air temperature) and O2 (oxygen sensor) signals are controlled via external potentiometers connected directly to the Speeduino ECU, independent of the ESP32.

---

## Pin Assignment Reference

### Digital Inputs

| GPIO | Physical Pin | Signal Name | Function | Electrical Characteristics | Notes |
|:----:|:---:|:---|:---|:---|:---|
| 4 | 26 | Start/Stop Button | Engine start/stop control | 3.3V logic; internal pull-up enabled | Button closes to GND when pressed |
| 27 | 12 | Fan Feedback | ECU fan activation status | 3.3V logic input | **Requires 5V→3.3V voltage divider or level shifter from Speeduino IDC Pin 15** |

### Analog Inputs

| GPIO | Physical Pin | ADC Channel | Signal Name | Function | Electrical Characteristics | Notes |
|:----:|:---:|:---:|:---|:---|:---|:---|
| 34 | 6 | ADC1_CH6 | TPS Monitor | Throttle position feedback | 0–3.3V; 12-bit ADC (4096 levels) | **Requires 5V→3.3V resistive divider from TPS potentiometer wiper** |

### Analog Outputs

| GPIO | Physical Pin | DAC Channel | Signal Name | Function | Output Range | Conditioning | Speeduino Connection |
|:----:|:---:|:---:|:---|:---|:---|:---|:---:|
| 25 | 10 | DAC1 | MAP Voltage | Manifold absolute pressure simulation | 0–3.3V (8-bit) | Op-amp amplifier (gain ≈ 1.5×) | IDC Pin 11 (MAP Sensor) |
| 26 | 11 | DAC2 | CLT Voltage | Coolant temperature simulation | 0–3.3V (8-bit) | Op-amp amplifier (gain ≈ 1.5×) | IDC Pin 19 (CLT Sensor) |

### Digital Outputs

| GPIO | Physical Pin | Signal Name | Function | Output Level | Conditioning | Speeduino Connection |
|:----:|:---:|:---|:---|:---:|:---|:---:|
| 12 | 14 | Crank Trigger | CKP signal generation | 3.3V CMOS | **3.3V→5V level shifter (74AHCT125)** | IDC Pin 25 (Crank Input / VR1+) |
| 13 | 16 | Cam1 Trigger | CMP1 signal generation | 3.3V CMOS | **3.3V→5V level shifter (74AHCT125)** | IDC Pin 24 (Cam Input / VR2+) |
| 14 | 13 | Cam2 Trigger | CMP2 signal generation | 3.3V CMOS | **3.3V→5V level shifter (74AHCT125)** | Optional; required for complex trigger wheels only |

### Common Signals

| Physical Pin | Signal | Purpose |
|:---:|:---|:---|
| — | GND | Common ground return (Speeduino ↔ ESP32) |

---

## Signals Managed Outside the ESP32

The following sensor inputs are controlled via external potentiometers connected directly to the Speeduino ECU, bypassing the ESP32:

| Sensor | Speeduino IDC Pin | Signal Path |
|:---|:---:|:---|
| IAT (Intake Air Temperature) | Pin 20 | External potentiometer → Speeduino |
| O2 (Oxygen Sensor / Lambda) | Pin 21 | External potentiometer → Speeduino |

---

## Signal Conditioning Requirements

### Voltage Level Shifting

**3.3V → 5V (Digital Outputs):**
- Devices: GPIO 12, 13, 14 (CKP and CMP signals)
- Conditioning: 74AHCT125 or equivalent level shifter
- Reason: Speeduino CKP/CMP inputs operate at 5V logic levels; ESP32 outputs are 3.3V

**5V → 3.3V (Digital & Analog Inputs):**
- Devices: GPIO 27 (Fan feedback), GPIO 34 (TPS input)
- Conditioning: Resistive voltage divider or dedicated level shifter module
- Reason: Speeduino outputs and external sensors operate at 5V; ESP32 ADC/GPIO inputs are 3.3V maximum

### Analog Amplification

**DAC Output Amplification (GPIO 25, 26):**
- Op-amp: TLV2372 (rail-to-rail) or equivalent
- Gain: Approximately 1.5×
- Input: 0–3.3V (ESP32 DAC)
- Output: 0–5V (Speeduino sensor inputs)
- Purpose: Stretch the 3.3V DAC range to match 5V Speeduino sensor input expectations for MAP and CLT

---

## Pinout Summary Table

| ESP32 GPIO | Type | Direction | Function | Conditioning | ECU / PCB Target |
|:---:|:----:|:---:|:---|:---|:---|
| 4 | D | Input | Start/Stop Button | Internal pull-up | Physical push button to GND |
| 12 | D | Output | Crank Trigger (CKP) | Level shifter (3V3→5V) | IDC Pin 25 |
| 13 | D | Output | Cam1 Trigger (CMP1) | Level shifter (3V3→5V) | IDC Pin 24 |
| 14 | D | Output | Cam2 Trigger (CMP2) | Level shifter (3V3→5V) | Optional |
| 25 | A | Output | MAP Sensor Output (DAC1) | Op-amp (gain ≈1.5×) | IDC Pin 11 |
| 26 | A | Output | CLT Sensor Output (DAC2) | Op-amp (gain ≈1.5×) | IDC Pin 19 |
| 27 | D | Input | Fan Feedback | Divider (5V→3V3) | IDC Pin 15 |
| 34 | A | Input | TPS Monitor (ADC1_CH6) | Divider (5V→3V3) | TPS potentiometer wiper |
| — | P | — | Ground (GND) | — | Common return (Speeduino & power rails) |

---

## Implementation Notes

1. **Level Shifters:** Use buffered level shifter ICs (e.g., 74AHCT125) rather than passive resistors for digital trigger outputs to maintain signal integrity and timing accuracy over CAN/wired connections.

2. **Pull-up Resistors:** GPIO 4 has an internal pull-up enabled in firmware. External pull-up is not required.

3. **ADC Filtering:** Consider adding RC low-pass filters (e.g., 10 kΩ + 100 nF) on GPIO 34 (TPS input) to suppress high-frequency noise.

4. **DAC Output Impedance:** The ESP32 DAC has significant output impedance (~1 kΩ); use a unity-gain buffer op-amp stage before the gain stage to isolate the DAC from load variations.

5. **Ground Plane:** Ensure a solid ground plane connection between the ESP32 PCB and the Speeduino ECU to minimize noise coupling on analog signals (MAP, CLT, TPS).

---

## References

- ESP32-WROOM-32U Datasheet
- Speeduino Standard 38-Pin ECU Connector (IDC) Pinout
- TLV2372 Op-amp Datasheet (signal conditioning)
- 74AHCT125 Level Shifter Datasheet (digital conditioning)

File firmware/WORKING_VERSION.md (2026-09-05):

# Versione Funzionante del Firmware

**Stato (2026-09-04):** questa versione e' confermata FUNZIONANTE su hardware (FASE 1).

**Stato (branch feature/fase2-timing-dashboard):** FASE 2 (timing iniettori/candele) e
FASE 3 (WiFi AP + dashboard web) in implementazione — NON ancora verificate su hardware.

## File di riferimento (versione funzionante)

- `Engine_Simulator_2.0.ino`
- `globals.h`
- `wheel_defs.h`
- `comms.h`, `comms.cpp`

Backup esplicito della versione funzionante:
- `Engine_Simulator_2.0_working_20260904.ino`
- `globals_working_20260904.h`
- `wheel_defs_working_20260904.h`

## Nuovi moduli (branch feature/fase2-timing-dashboard)

- `timing.h`, `timing.cpp` — input capture su ISR dei 9 canali Speeduino letti via
  CD4050BE (4 iniettori + 4 candele + fan). Misura on-time iniettore (ms), frequenza,
  duty, dwell candela e anticipo in gradi rispetto al fronte Crank (l'ESP32 e' il master).
- `web.h`, `web.cpp` — WiFi AP (`EngineSimulator2.0` / `1234567890` / `192.168.254.1`),
  dashboard web su `/`, setup ruota fonica su `/setup`, endpoint `/api/data` JSON,
  salvataggio `config.wheel` su NVS (namespace `engsim`, key `wheel`).

## Dipendenze librerie aggiuntive

Il firmware ora richiede anche:
- **ESP Async WebServer** (fork `ESP32Async`, qui usato v3.9.4):
  `https://github.com/ESP32Async/ESPAsyncWebServer`
- **Async TCP** (fork `ESP32Async`, dipendenza di ESP Async WebServer, qui v3.5.0):
  `https://github.com/ESP32Async/AsyncTCP`

> **IMPORTANTE**: le versioni originali `me-no-dev` (`ESPAsyncWebServer` 3.1.0 e
> `AsyncTCP` 1.1.4, installate con il nome classico) NON compilano con ESP32 Core v3.3.11:
> la 3.1.0 usa `mbedtls_md5_*_ret` (rimosse da mbedTLS 3) e la 1.1.4 manca del qualifier
> `const` su `AsyncServer::status()`. Vanno quindi usati i fork `ESP32Async`
> (`ESP Async WebServer` + `Async TCP`), che espongono gli stessi header
> (`ESPAsyncWebServer.h`, `AsyncTCP.h`).

Tutte le altre librerie sono di base dell'ESP32 Arduino Core.

## Corriszione critica inclusa (2026-09)

Sulla ISR del timer `onCrankTimer()` l'uso di `digitalWrite()` NON aggiornava i pin
GPIO su ESP32 Arduino Core v3.3.5 (Crank/Cam restavano a 0V anche a motore avviato,
quindi Speeduino non leggeva i giri).

**Fix applicata:** sostituito `digitalWrite` con la scrittura diretta ai registri GPIO:
- HIGH: `GPIO.out_w1ts = (1ULL << pin);`
- LOW:  `GPIO.out_w1tc = (1ULL << pin);`

Include aggiunti: `soc/gpio_struct.h` e `soc/gpio_reg.h`.

La stessa tecnica (accesso diretto a `GPIO.in`) e' usata nelle ISR di input capture
di `timing.cpp` (NON usare `digitalRead`/`digitalWrite` dentro le ISR su core v3.3.5).

## Verifica hardware

- Scheda: ESP32 DevKit1 (ESP32-D0WD-V3) su COM4
- Collegamento Crank (GPIO12) / Cam1 (GPIO13) / Cam2 (GPIO14) a 3.3V
- Speeduino (Mega2560) legge correttamente i giri
- Tensione media su Crank/Cam: ~1.6V (square 3.3V, duty ~50%)

## Comando di compilazione

```bash
arduino-cli compile --fqbn esp32:esp32:esp32 firmware/Engine_Simulator_2.0.ino

# prima installazione delle librerie (NOMI ESATTI dei fork ESP32Async)
arduino-cli lib install "ESP Async WebServer" "Async TCP"

arduino-cli upload -p COM4 --fqbn esp32:esp32:esp32 firmware/Engine_Simulator_2.0.ino
```

> Nota: arduino-cli richiede che lo sketch stia in una cartella con lo stesso nome del file
> `.ino`. La copia pronta per Arduino IDE e' in `../Engine_Simulator_2_0/` (allineata al
> codice nella branch).

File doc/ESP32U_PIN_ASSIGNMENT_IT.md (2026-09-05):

# Assegnazione Pin ESP32U - Engine Simulator 2.0

Assegnazione pin sul modulo **ESP32-WROOM-32U** per il simulatore di motore.

L'ESP32U si distingue per la presenza del connettore U.FL per l'antenna esterna, ma mantiene la stessa piedinatura e pinout standard dei moduli ESP32 WROOM a 38 pin.

---

## Architettura Segnali

L'ESP32 si occupa esclusivamente di:
- **Generare** i segnali di ruota fonica (Crank, Cam1, Cam2)
- **Generare** le tensioni analogiche per MAP e CLT verso Speeduino
- **Leggere** il TPS (per controllare gli RPM) e lo stato della ventola
- **Gestire** il pulsante Start/Stop

I segnali IAT e O2 sono gestiti **manualmente** tramite potenziometri collegati direttamente a Speeduino, senza intervento dell'ESP32.

---

## Mappa dei Collegamenti Pin ESP32U

### Ingressi Digitali & Pulsanti
*   **GPIO 4** (Pin 26): **Pulsante Start/Stop**
    *   *Descrizione:* Ingresso digitale per avviare/arrestare il motore.
    *   *Nota:* Configurato con pull-up interno. Il pulsante deve chiudere verso GND.

*   **GPIO 27** (Pin 12): **Input Stato Ventola (ECU Fan Feedback)**
    *   *Descrizione:* Rileva se Speeduino ha attivato la ventola di raffreddamento.
    *   *Nota:* Speeduino lavora a 5V. **Richiede partitore resistivo o level shifter (5V -> 3.3V)** prima di arrivare a questo pin. Attivo a livello logico basso (GND = Ventola accesa).
    *   *Collegamento Speeduino:* IDC Pin 15 (Proto Area 2 / Fan)

---

### Ingressi Analogici (Sensori)
*   **GPIO 34** (Pin 6 - ADC1_CH6): **Ingresso Potenziometro TPS (Acceleratore)**
    *   *Descrizione:* Legge il valore del reostato dell'acceleratore per determinare il target RPM.
    *   *Nota:* Il potenziometro TPS del simulatore e' alimentato a 5V (condiviso con Speeduino). Il cursore centrale va collegato a questo pin dell'ESP32 **esclusivamente tramite partitore resistivo** (es. 10k e 20k ohm) per limitare la tensione massima a 3.3V. Lo stesso segnale va anche al pin TPS di Speeduino (IDC Pin 22).
    *   *Collegamento Speeduino:* IDC Pin 22 (TPS) - parte comune del potenziometro

*   **GPIO 35 e GPIO 32**: **NON UTILIZZATI** dall'ESP32. IAT e O2 sono gestiti da potenziometri collegati direttamente a Speeduino.

---

### Uscite Analogiche (Simulazione Sensori per ECU)
*   **GPIO 25** (Pin 10 - DAC1): **Output Analogico MAP (Pressione)**
    *   *Descrizione:* Uscita analogica (DAC 8-bit) che genera la tensione di pressione del collettore in base alla dinamica del motore.
    *   *Nota:* Genera un segnale 0-3.3V. Per interfacciarsi con i 5V di Speeduino, viene utilizzato un amplificatore operazionale TLV2372 con guadagno ~1.5x per coprire il range 0-5V.
    *   *Collegamento Speeduino:* IDC Pin 11 (MAP Sensor)

*   **GPIO 26** (Pin 11 - DAC2): **Output Analogico CLT (Temperatura Motore)**
    *   *Descrizione:* Uscita analogica (DAC 8-bit) che genera la tensione della temperatura dell'acqua simulando la curva termica.
    *   *Nota:* Genera un segnale 0-3.3V. Amplificato a 0-5V tramite op-amp per Speeduino.
    *   *Collegamento Speeduino:* IDC Pin 19 (CLT)

---

### Uscite Digitali (Generazione Ruote Foniche)
*   **GPIO 12** (Pin 14): **Crank Trigger Output** (Giri Motore)
    *   *Descrizione:* Genera l'onda quadra per il sensore di giri (CKP).
    *   *Nota:* **Richiede level shifter digitale 3.3V -> 5V** (74AHCT125) prima di andare al pin Crank di Speeduino.
    *   *Collegamento Speeduino:* IDC Pin 25 (Crank Input / VR1+)

*   **GPIO 13** (Pin 16): **Cam 1 Trigger Output** (Fase Motore)
    *   *Descrizione:* Genera il segnale per il sensore di fase 1 (CMP1).
    *   *Nota:* **Richiede level shifter digitale 3.3V -> 5V** (74AHCT125).
    *   *Collegamento Speeduino:* IDC Pin 24 (Cam Input / VR2+)

*   **GPIO 14** (Pin 13): **Cam 2 Trigger Output** (Fase Motore Secondaria)
    *   *Descrizione:* Genera il segnale di fase secondario (CMP2) per ruote foniche complesse.
    *   *Nota:* **Richiede level shifter digitale 3.3V -> 5V** (74AHCT125). Non sempre necessario.

---

## Riassunto Tabellare Pinout ESP32U

| Nome Pin ESP32U | Tipo | Direzione | Funzione nel Simulatore | Collegamento ECU / PCB |
|:---:|:----:|:---:|:---:|:---|
| **GPIO 4** | D | Input | Pulsante Start/Stop | Pulsante fisico a GND |
| **GPIO 12** | D | Output | Crank Trigger | Level Shifter -> IDC Pin 25 |
| **GPIO 13** | D | Output | Cam 1 Trigger | Level Shifter -> IDC Pin 24 |
| **GPIO 14** | D | Output | Cam 2 Trigger | Level Shifter (opzionale) |
| **GPIO 25** | A | Output | MAP Sensor (DAC1) | Op-amp (guadagno 1.5x) -> IDC Pin 11 |
| **GPIO 26** | A | Output | CLT Sensor (DAC2) | Op-amp -> IDC Pin 19 |
| **GPIO 27** | D | Input | Feedback Ventola (FAN)  | Partitore 5V->3.3V <- IDC Pin 15 |
| **GPIO 34** | A | Input | Monitor TPS | Partitore <- Potenziometro TPS |
| **GND** | P | - | Massa Comune | GND comune Speeduino/ESP32 |

---

## Pin NON Utilizzati dall'ESP32

I seguenti segnali sono gestiti **senza intervento dell'ESP32** (potenziometri manuali collegati direttamente a Speeduino):

| Segnale | Pin IDC Speeduino | Note |
|:---|:---:|:-----|
| IAT (Temperatura Aria) | IDC Pin 20 | Potenziometro esterno, direttamente a Speeduino |
| O2 (Sonda Lambda) | IDC Pin 21 | Potenziometro esterno, direttamente a Speeduino |

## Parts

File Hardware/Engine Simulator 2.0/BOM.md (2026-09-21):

# BOM — Engine Simulator 2.0

Bill of Materials automaticamente estratta dal netlist dello schema KiCad.
**Da aggiornare a ogni modifica di schema/PCB** (rigenerare dal netlist).

- Progetto: `Hardware/Engine Simulator 2.0/Engine Simulator 2.0.kicad_sch`
- Ultima estrazione: 2026-09-21
- Componenti totali: **58**
- Formato: TH (through-hole) — salvo ESP32 (module premontato su DevKitC)

| Ref | Qta | Valore | Footprint | Note |
|:----|:---:|:---|:---|:-----|
| C1 | 1 | 0.33 uF | Capacitor_THT:C_Disc_D10.5mm_W5.0mm_P5.00mm | Filtro ingresso alimentazione |
| C2, C3, C6 | 3 | 0.1 uF | Capacitor_THT:C_Disc_D10.5mm_W5.0mm_P5.00mm | Disaccoppiamento locale |
| C4 | 1 | 470 uF | PCM_Capacitor_THT_AKL:CP_Radial_D5.0mm_P2.00mm | Bulk ingresso 12V |
| C5 | 1 | 47 uF | PCM_Capacitor_THT_AKL:CP_Radial_D5.0mm_P2.00mm | Bulk uscita 5V |
| C7 | 1 | 470 uF 16V | PCM_Capacitor_THT_AKL:CP_Radial_D5.0mm_P2.00mm | Dopo D13 (protezione inversa) |
| D13 | 1 | 1N5817 | Diode_THT:D_DO-41_SOD81_P10.16mm_Horizontal | Diodo Schottky protezione polarita' inversa |
| DZ1–DZ9 | 9 | BZX55-C3V6 | PCM_Diode_THT_AKL:D_DO-35_SOD27_P7.62mm_Horizontal_Zener | Zener 3.6V, protezione ingressi CD4050 |
| J1 | 1 | ~ | Connector_IDC:IDC-Header_2x20_P2.54mm_Latch_Vertical | Connettore IDC 40-pin verso Speeduino |
| J2 | 1 | DC IN | TerminalBlock_Altech:Altech_AK100_1x02_P5.00mm | Morsettiera alimentazione 12V |
| J3–J9, J11 | 8 | ~ | TerminalBlock_Altech:Altech_AK100_1x02_P5.00mm | Morsettiere uscite/potenziometri |
| J10 | 1 | CRANK | TerminalBlock_Altech:Altech_AK100_1x02_P5.00mm | Morsettiera segnale crank |
| J12 | 1 | Screw_Terminal_01x02 | TerminalBlock_Altech:Altech_AK100_1x02_P5.00mm | Morsettiera |
| R13, R14, R16, R18, R21 | 5 | 10 kOhm | Resistor_THT:R_Axial_DIN0207_L6.3mm_D2.5mm_P7.62mm_Horizontal | Partitori / pull-up |
| R15, R17 | 2 | 5.1 kOhm | Resistor_THT:R_Axial_DIN0207_L6.3mm_D2.5mm_P7.62mm_Horizontal | Partitori |
| R22 | 1 | 20 kOhm | Resistor_THT:R_Axial_DIN0207_L6.3mm_D2.5mm_P7.62mm_Horizontal | Partitore ingresso fan |
| R23–R31 | 9 | 2.2 kOhm | Resistor_THT:R_Axial_DIN0207_L6.3mm_D2.5mm_P7.62mm_Horizontal | Rete R serie protezione CD4050 (9 canali) |
| RV1, RV2 | 2 | 2 kOhm | Potentiometer_THT:Potentiometer_ACP_CA6-H2,5_Horizontal | Trimmer |
| RV3–RV5 | 3 | 10 kOhm | Potentiometer_THT:Potentiometer_ACP_CA9-V10_Vertical | Trimmer TPS/IAT/O2 |
| SW2 | 1 | Start/Stop | Button_Switch_THT:SW_PUSH_1P1T_6x3.5mm_H5.0_APEM_MJTP1250 | Pulsante start/stop motore |
| U1 | 1 | ESP32-DevKitC | PCM_Espressif:ESP32-DevKitC | Microcontrollore principale |
| U2 | 1 | 74AHCT125 | Package_DIP:DIP-14_W7.62mm_LongPads | Quad level shifter 3.3V->5V (Crank/Cam1/Cam2) |
| U3 | 1 | R-78E5.0-1.0 | Converter_DCDC:Converter_DCDC_RECOM_R-78E-0.5_THT | Regolatore switching 5V/1A drop-in 7805 |
| U4 | 1 | TLV2372 | Package_DIP:DIP-8_W7.62mm_Socket_LongPads | Doppio op-amp rail-to-rail (MAP/CLT buffer) |
| U5, U6 | 2 | CD4050BE | Package_DIP:DIP-16_W7.62mm_LongPads | Hex buffer ingressi ECU (4 inj + 4 ign + fan) |

## Note

- **U3**: footprint `-0.5_THT` usato come drop-in per la versione 1.0A (stesso package SIP3, pinout identico, pad 1.5x2.3 mm). Fornitore consigliato: Conrad.it (~4.79 EUR). RS Italia (cod. 144-6290) non disponibile.
- **U2**: un solo chip 74AHCT125 (4 buffer) copre Crank, Cam1, Cam2 e uno di riserva.
- **U4**: un solo chip TLV2372 (2 op-amp) copre i buffer MAP e CLT.
- **DZ1–DZ9 + R23–R31**: rete di protezione (Zener 3.6V clamp) prima degli ingressi CD4050, 9 canali.
- **Connettori**: J1 = IDC 40-pin verso Speeduino; morsettiere a vite 5.00 mm per cablaggio esterno.

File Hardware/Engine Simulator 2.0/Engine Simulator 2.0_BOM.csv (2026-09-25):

Reference | Qty | Value | DNP | Exclude from BOM | Exclude from Board | Footprint | Datasheet
C1 | 1 | 0.33 uF |  |  |  | Capacitor_THT:C_Disc_D10.5mm_W5.0mm_P5.00mm
C2,C3,C6 | 3 | 0.1uF |  |  |  | Capacitor_THT:C_Disc_D10.5mm_W5.0mm_P5.00mm
C4 | 1 | 470uf |  |  |  | PCM_Capacitor_THT_AKL:CP_Radial_D5.0mm_P2.00mm
C5 | 1 | 47uf |  |  |  | PCM_Capacitor_THT_AKL:CP_Radial_D5.0mm_P2.00mm
C7 | 1 | 470 uf 16v |  |  |  | PCM_Capacitor_THT_AKL:CP_Radial_D5.0mm_P2.00mm
D13 | 1 | 1N5817 |  |  |  | Diode_THT:D_DO-41_SOD81_P10.16mm_Horizontal | http://www.vishay.com/docs/88525/1n5817.pdf
DZ1,DZ2,DZ3,DZ4,DZ5,DZ6,DZ7,DZ8,DZ9 | 9 | BZX55-C3V6 |  |  |  | PCM_Diode_THT_AKL:D_DO-35_SOD27_P7.62mm_Horizontal_Zener | https://www.tme.eu/Document/9906bac3657dc59bd4a6884b643c759b/1N52xxB.pdf
J1 | 1 |  |  |  |  | Connector_IDC:IDC-Header_2x20_P2.54mm_Latch_Vertical
J2 | 1 | DC IN |  |  |  | TerminalBlock_Altech:Altech_AK100_1x02_P5.00mm
J3,J4,J5,J6,J7,J8,J9,J11 | 8 |  |  |  |  | TerminalBlock_Altech:Altech_AK100_1x02_P5.00mm
J10 | 1 | CRANK |  |  |  | TerminalBlock_Altech:Altech_AK100_1x02_P5.00mm
J12 | 1 | Screw_Terminal_01x02 |  |  |  | TerminalBlock_Altech:Altech_AK100_1x02_P5.00mm
R13,R14,R16,R18,R21 | 5 | 10k |  |  |  | Resistor_THT:R_Axial_DIN0207_L6.3mm_D2.5mm_P7.62mm_Horizontal
R15,R17 | 2 | 5.1k |  |  |  | Resistor_THT:R_Axial_DIN0207_L6.3mm_D2.5mm_P7.62mm_Horizontal
R22 | 1 | 20k |  |  |  | Resistor_THT:R_Axial_DIN0207_L6.3mm_D2.5mm_P7.62mm_Horizontal
R23,R24,R25,R26,R27,R28,R29,R30,R31 | 9 | 2.2k |  |  |  | Resistor_THT:R_Axial_DIN0207_L6.3mm_D2.5mm_P7.62mm_Horizontal
RV1,RV2 | 2 | 2k |  |  |  | Potentiometer_THT:Potentiometer_ACP_CA6-H2,5_Horizontal
RV3,RV4,RV5 | 3 | 10k |  |  |  | Potentiometer_THT:Potentiometer_ACP_CA9-V10_Vertical
SW2 | 1 | Start/Stop |  |  |  | Button_Switch_THT:SW_PUSH_1P1T_6x3.5mm_H5.0_APEM_MJTP1250
U1 | 1 | ESP32-DevKitC |  |  |  | PCM_Espressif:ESP32-DevKitC | https://docs.espressif.com/projects/esp-idf/zh_CN/latest/esp32/hw-reference/esp32/get-started-devkitc.html
U2 | 1 | 74AHCT125 |  |  |  | Package_DIP:DIP-14_W7.62mm_LongPads | https://www.ti.com/lit/ds/symlink/sn74ahct125.pdf
U3 | 1 | R-78E5.0-1.0 |  |  |  | Converter_DCDC:Converter_DCDC_RECOM_R-78E-0.5_THT | https://www.recom-power.com/pdf/Innoline/R-78E-1.0.pdf
U4 | 1 | TLV2372 |  |  |  | Package_DIP:DIP-8_W7.62mm_Socket_LongPads | http://www.ti.com/lit/ds/symlink/tlv2375.pdf
U5,U6 | 2 | CD4050BE |  |  |  | Package_DIP:DIP-16_W7.62mm_LongPads | https://www.ti.com/lit/gpn/cd4050b

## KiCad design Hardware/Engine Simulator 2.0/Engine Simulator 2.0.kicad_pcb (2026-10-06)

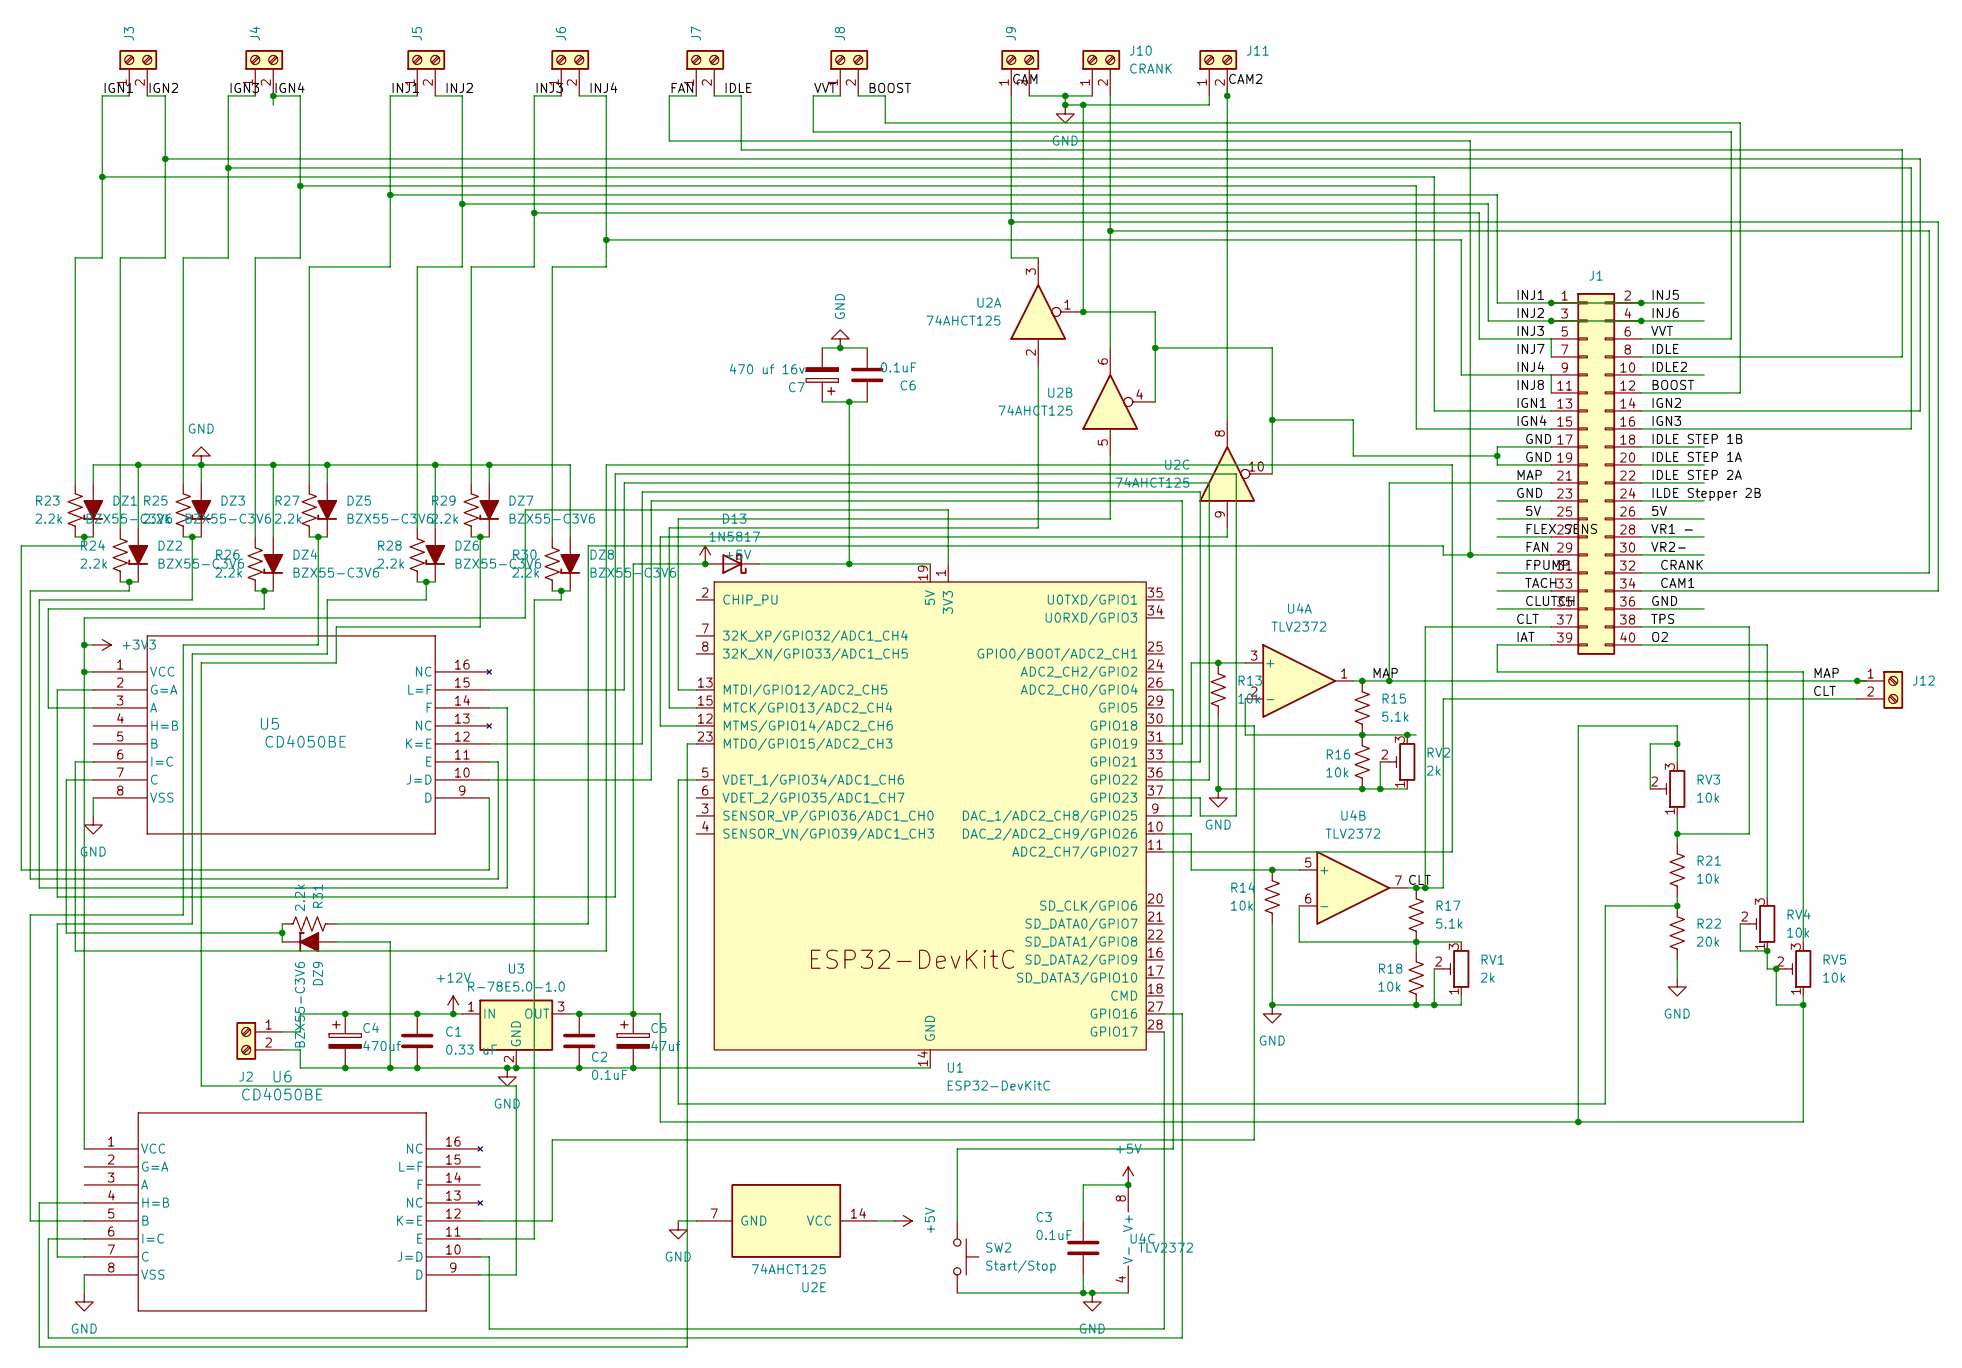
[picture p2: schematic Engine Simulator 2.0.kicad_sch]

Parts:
C1: 0.33 uF; C_Disc_D10.5mm_W5.0mm_P5.00mm
C2, C3, C6: 0.1uF; C_Disc_D10.5mm_W5.0mm_P5.00mm
C4: 470uf; CP_Radial_D5.0mm_P2.00mm
C5: 47uf; CP_Radial_D5.0mm_P2.00mm
C7: 470 uf 16v; CP_Radial_D5.0mm_P2.00mm
D13: 1N5817; D_DO-41_SOD81_P10.16mm_Horizontal
DZ1, DZ2, DZ3, DZ4, DZ5, DZ6, DZ7, DZ8, DZ9: BZX55-C3V6; D_DO-35_SOD27_P7.62mm_Horizontal_Zener
J1: IDC-Header_2x20_P2.54mm_Vertical
J2: DC IN; Altech_AK100_1x02_P5.00mm
J3, J4, J5, J6, J7, J8, J9, J11: Altech_AK100_1x02_P5.00mm
J10: CRANK; Altech_AK100_1x02_P5.00mm
J12: Screw_Terminal_01x02; Altech_AK100_1x02_P5.00mm
R13, R14, R16, R18, R21: 10k; R_Axial_DIN0207_L6.3mm_D2.5mm_P7.62mm_Horizontal
R15, R17: 5.1k; R_Axial_DIN0207_L6.3mm_D2.5mm_P7.62mm_Horizontal
R22: 20k; R_Axial_DIN0207_L6.3mm_D2.5mm_P7.62mm_Horizontal
R23, R24, R25, R26, R27, R28, R29, R30, R31: 2.2k; R_Axial_DIN0207_L6.3mm_D2.5mm_P7.62mm_Horizontal
RV1, RV2: 2k; Potentiometer_ACP_CA6-H2,5_Horizontal
RV3, RV4, RV5: 10k; Potentiometer_ACP_CA9-V10_Vertical
SW2: Start/Stop; SW_PUSH_1P1T_6x3.5mm_H5.0_APEM_MJTP1250
U1: ESP32-DevKitC
U2: 74AHCT125; DIP-14_W7.62mm_LongPads
U3: R-78E5.0-1.0; Converter_DCDC_RECOM_R-78E-0.5_THT
U4: TLV2372; DIP-8_W7.62mm_Socket_LongPads
U5, U6: CD4050BE; DIP-16_W7.62mm_LongPads

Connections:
+3V3: U1.1 (3V3), U5.1 (VCC), U6.1 (VCC)
+5V: C2.1, C3.1, C5.1, D13.2 (A), RV3.2, RV3.3, RV4.1, RV4.2, RV5.1, RV5.2, U2.14 (VCC), U3.3 (OUT), U4.8 (V+)
+12V: C1.1, C4.1, J2.1, U3.1 (IN)
/5V: J1.25, J1.26
/BOOST: J1.12, J8.2
/CAM1: J1.34, J9.1, U2.3
/CAM2: J11.2, U2.8
/CLT: J1.37, J12.2, R17.1, U4.7
/CLUTCH: J1.35
/CRANK: J1.32, J10.2, U2.6
/FAN: J1.29, J7.1, R31.1
/FLEX SENS: J1.27
/FPUMP: J1.31
/IAT: J1.39, RV5.3
/IDLE: J1.8, J7.2
/IDLE2: J1.10
/IDLE STEP 1A: J1.20
/IDLE STEP 1B: J1.18
/IDLE STEP 2A: J1.22
/IGN1: J1.13, J3.1, R23.1
/IGN2: J1.14, J3.2, R24.1
/IGN3: J1.16, J4.1, R25.1
/IGN4: J1.15, J4.2, R26.1
/ILDE Stepper 2B: J1.24
/INJ1: J1.1, J1.2, J5.1, R27.1
/INJ2: J1.3, J1.4, J5.2, R28.1
/INJ3: J1.5, J1.7, J6.1, R29.1
/INJ4: J1.9, J1.11, J6.2, R30.1
/MAP: J1.21, J12.1, R15.1, U4.1
/O2: J1.40, RV4.3
/TACH: J1.33
/TPS: J1.38, R21.1, RV3.1
/VR1 -: J1.28
/VR2-: J1.30
/VVT: J1.6, J8.1
GND: C1.2, C2.2, C3.2, C4.2, C5.2, C6.2, C7.2, DZ1.2 (A), DZ2.2 (A), DZ3.2 (A), DZ4.2 (A), DZ5.2 (A), DZ6.2 (A), DZ7.2 (A), DZ8.2 (A), DZ9.2 (A), J1.17, J1.19, J1.23, J1.36, J2.2, J9.2, J10.1, J11.1, R13.2, R14.2, R16.2, R18.2, R22.2, RV1.1, RV1.2, RV2.1, RV2.2, SW2.2, U1.14 (GND), U1.32 (GND), U1.38 (GND), U2.1, U2.4, U2.7 (GND), U2.10, U3.2 (GND), U4.4 (V-), U5.8 (VSS), U6.8 (VSS); also elsewhere on the board
unnamed: C6.1, C7.1, D13.1 (K), U1.19 (5V)
unnamed: DZ1.1 (K), R23.2, U5.9 (D)
unnamed: DZ2.1 (K), R24.2, U5.11 (E)
unnamed: DZ3.1 (K), R25.2, U5.14 (F)
unnamed: DZ4.1 (K), R26.2, U5.3 (A)
unnamed: DZ5.1 (K), R27.2, U6.5 (B)
unnamed: DZ6.1 (K), R28.2, U6.7 (C)
unnamed: DZ7.1 (K), R29.2, U6.9 (D)
unnamed: DZ8.1 (K), R30.2, U6.11 (E)
unnamed: DZ9.1 (K), R31.2, U5.7 (C)
unnamed: SW2.1, U1.26 (ADC2_CH0/GPIO4)
unnamed: U1.11 (ADC2_CH7/GPIO27), U5.6 (I=C)
unnamed: R13.1, U1.9 (DAC_1/ADC2_CH8/GPIO25), U4.3 (+)
unnamed: R14.1, U1.10 (DAC_2/ADC2_CH9/GPIO26), U4.5 (+)
unnamed: U1.27 (GPIO16), U6.6 (I=C)
unnamed: U1.28 (GPIO17), U6.10 (J=D)
unnamed: U1.30 (GPIO18), U6.12 (K=E)
unnamed: U1.31 (GPIO19), U5.10 (J=D)
unnamed: U1.33 (GPIO21), U5.12 (K=E)
unnamed: U1.36 (GPIO22), U5.15 (L=F)
unnamed: U1.37 (GPIO23), U5.2 (G=A)
unnamed: U1.15 (MTCK/GPIO13/ADC2_CH4), U2.2
unnamed: U1.13 (MTDI/GPIO12/ADC2_CH5), U2.5
unnamed: U1.23 (MTDO/GPIO15/ADC2_CH3), U6.4 (H=B)
unnamed: U1.12 (MTMS/GPIO14/ADC2_CH6), U2.9
unnamed: R21.2, R22.1, U1.5 (VDET_1/GPIO34/ADC1_CH6)
unnamed: R15.2, R16.1, RV2.3, U4.2 (-)
unnamed: R17.2, R18.1, RV1.3, U4.6 (-)

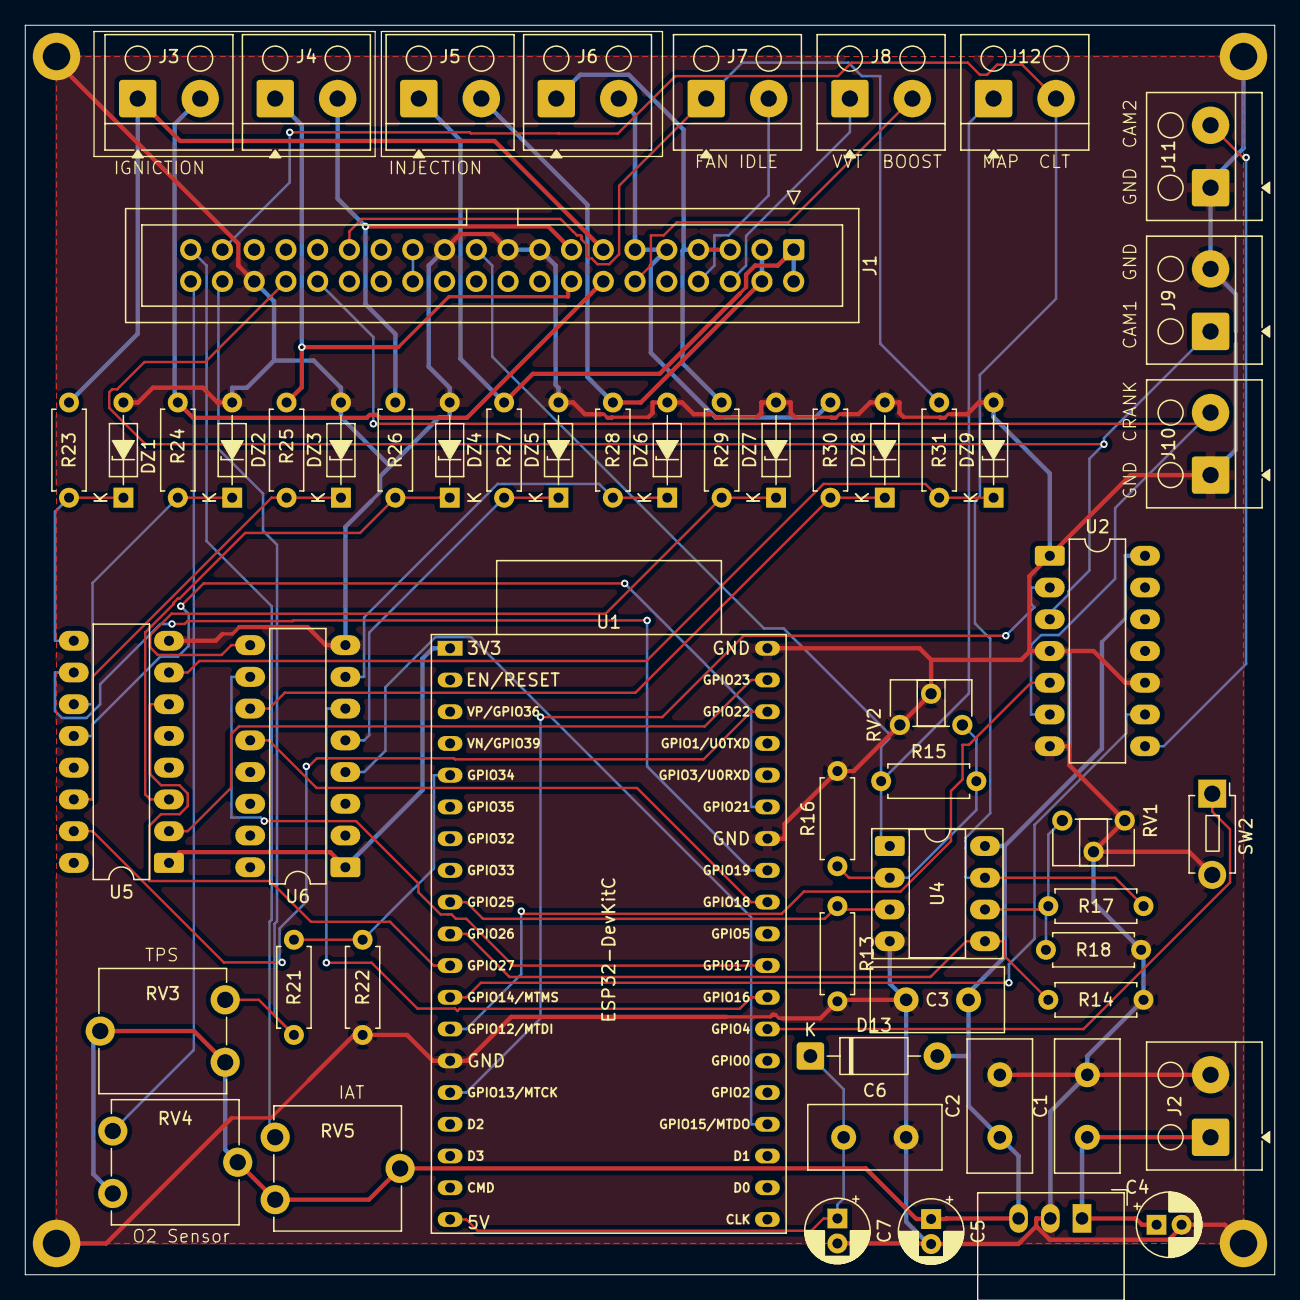
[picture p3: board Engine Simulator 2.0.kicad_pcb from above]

Board: 2 copper layers, 100.0 x 100.0 mm, 62 parts (0 on the bottom side), 53 nets.

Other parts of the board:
MH1, MH2, MH3, MH4: MountingHole_2.2mm_M2_DIN965_Pad

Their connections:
GND: MH1.1, MH2.1, MH3.1, MH4.1; also elsewhere on the board

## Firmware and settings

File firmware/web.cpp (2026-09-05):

/*
 * web.cpp - WiFi AP + dashboard web + endpoint /api/data (FASE 3)
 *
 * Access Point fissi:
 *   SSID: EngineSimulator2.0 | Pass: 1234567890 | IP: 192.168.254.1 (DHCP per i client)
 *
 * Route:
 *   /            -> dashboard motore (HTML statico, aggiornamento via /api/data)
 *   /setup       -> selezione ruota fonica/cam + salvataggio su NVS
 *   /api/data    -> JSON con stato motore + timing iniettori/candele
 *   /api/wheel   -> POST: salva config.wheel su NVS (chiamato da /setup)
 *
 * Nota: ESPAsyncWebServer gira sul core 0 (asincrono, non blocca la simulazione).
 */

#include "web.h"
#include "globals.h"
#include "timing.h"
#include "comms.h"
#include <WiFi.h>
#include <ESPAsyncWebServer.h>
#include <Preferences.h>

extern wheels Wheels[];

static AsyncWebServer server(80);
static Preferences prefs;

// --- HELPERS ---
static const char *engineStateName() {
  switch (engineState) {
    case ENGINE_OFF:       return "OFF";
    case ENGINE_CRANKING:  return "CRANKING";
    case ENGINE_RUNNING:   return "RUNNING";
    case ENGINE_STOPPING:  return "STOPPING";
    default:               return "UNKNOWN";
  }
}

static String wheelName(uint8_t idx) {
  char buf[60];
  strcpy_P(buf, Wheels[idx].decoder_name);
  return String(buf);
}

// --- HTML DASHBOARD (statico, JS popola via /api/data) ---
const char INDEX_HTML[] PROGMEM = R"HTML(
<!DOCTYPE html>
<html lang="it">
<head>
<meta charset="UTF-8">
<meta name="viewport" content="width=device-width, initial-scale=1.0">
<title>Engine Simulator 2.0</title>
<style>
:root{
  --bg:#0b0f14; --panel:#141b24; --panel2:#1a232e; --line:#263341;
  --txt:#e6edf3; --dim:#8ba0b4; --acc:#00d4ff; --ok:#22c55e; --warn:#f59e0b;
  --hot:#ef4444; --rpm:#00d4ff;
}
*{margin:0;padding:0;box-sizing:border-box}
body{
  background:radial-gradient(1200px 700px at 70% -10%,#12202e 0%,var(--bg) 55%);
  color:var(--txt); font-family:'Segoe UI',system-ui,sans-serif; min-height:100vh; padding:16px;
}
.wrap{max-width:1180px;margin:0 auto}
header{
  display:flex;align-items:center;justify-content:space-between;gap:12px;flex-wrap:wrap;
  padding:14px 18px;background:var(--panel);border:1px solid var(--line);border-radius:14px;
  box-shadow:0 4px 24px rgba(0,0,0,.35);
}
.brand{display:flex;align-items:center;gap:12px}
.brand .logo{
  width:42px;height:42px;border-radius:11px;display:grid;place-items:center;font-size:22px;
  background:linear-gradient(135deg,#0e2a3a,#123);border:1px solid var(--line);
}
.brand h1{font-size:1.15rem;font-weight:700;letter-spacing:.4px}
.brand small{display:block;color:var(--dim);font-size:.72rem;letter-spacing:1.4px;text-transform:uppercase}
.statebox{display:flex;align-items:center;gap:14px}
#state-badge{
  font-size:.78rem;font-weight:800;letter-spacing:1.6px;padding:7px 14px;border-radius:999px;
  background:#1a2430;border:1px solid var(--line);color:var(--dim);transition:all .3s;
}
#state-badge.on{background:rgba(34,197,94,.12);border-color:var(--ok);color:var(--ok);box-shadow:0 0 14px rgba(34,197,94,.35)}
#state-badge.crank{background:rgba(245,158,11,.12);border-color:var(--warn);color:var(--warn)}
#state-badge.stop{background:rgba(239,68,68,.12);border-color:var(--hot);color:var(--hot)}
.wifi-dot{width:11px;height:11px;border-radius:50%;background:var(--hot);transition:background .3s}
.wifi-dot.on{background:var(--ok);box-shadow:0 0 10px var(--ok)}
#client-count{font-size:.75rem;color:var(--dim)}
nav{display:flex;gap:8px;margin-top:14px}
nav a{
  text-decoration:none;color:var(--dim);font-size:.82rem;font-weight:600;letter-spacing:.5px;
  padding:8px 16px;border-radius:10px;border:1px solid transparent;transition:all .2s;
}
nav a:hover{color:var(--txt);border-color:var(--line);background:var(--panel2)}
nav a.active{color:var(--acc);border-color:var(--acc);background:rgba(0,212,255,.07)}
.grid{display:grid;grid-template-columns:1fr 1fr;gap:14px;margin-top:14px}
@media(max-width:900px){.grid{grid-template-columns:1fr}}
.card{background:var(--panel);border:1px solid var(--line);border-radius:14px;padding:16px;
  box-shadow:0 4px 20px rgba(0,0,0,.28)}
.card h2{font-size:.78rem;color:var(--dim);text-transform:uppercase;letter-spacing:1.4px;margin-bottom:10px}

/* Gauge RPM */
.gauge{position:relative;width:100%;max-width:340px;margin:0 auto}
.gauge svg{width:100%;display:block}
#rpm-num{font-size:2.6rem;font-weight:800;fill:var(--rpm);text-anchor:middle}
#rpm-label{font-size:.68rem;fill:var(--dim);text-anchor:middle;letter-spacing:1px}
#rpm-val{text-align:center;font-size:1.9rem;font-weight:800;color:var(--rpm);margin-top:8px;
  font-variant-numeric:tabular-nums;text-shadow:0 0 18px rgba(0,212,255,.45)}
#rpm-unit{font-size:.75rem;color:var(--dim);margin-left:5px;font-weight:600}

/* Barre */
.bar-band{display:flex;align-items:center;gap:12px;margin:10px 0}
.bar-l{width:72px;font-size:.8rem;color:var(--dim);font-weight:700}
.bar{flex:1;height:14px;background:#0d141c;border-radius:8px;border:1px solid var(--line);overflow:hidden}
.bar-f{height:100%;width:0%;border-radius:8px;transition:width .35s cubic-bezier(.22,1,.36,1)}
.bar-v{width:78px;text-align:right;font-size:.9rem;font-weight:700;font-variant-numeric:tabular-nums}
.mini{display:grid;grid-template-columns:1fr 1fr;gap:14px;margin-top:4px}
.mini .item{background:var(--panel2);border:1px solid var(--line);border-radius:10px;padding:10px 12px}
.mini .k{font-size:.68rem;color:var(--dim);text-transform:uppercase;letter-spacing:1px}
.mini .v{font-size:1.15rem;font-weight:700;margin-top:3px}

/* Timing tables */
table{width:100%;border-collapse:collapse;font-size:.82rem}
th{color:var(--dim);text-align:left;font-size:.68rem;text-transform:uppercase;letter-spacing:1px;padding:6px 8px;border-bottom:1px solid var(--line)}
td{padding:7px 8px;border-bottom:1px solid rgba(38,51,65,.5)}
td.ch{font-weight:700}
.val-in{color:var(--acc)}
.val-ig{color:var(--warn)}
.on{color:var(--ok)}
.off{color:var(--dim)}
.led{display:inline-block;width:9px;height:9px;border-radius:50%;margin-right:6px;vertical-align:middle}
.led.on{background:var(--ok);box-shadow:0 0 8px var(--ok)}
.led.off{background:#3a4a5a}

/* Setup */
select{
  width:100%;padding:11px 12px;border-radius:10px;background:var(--panel2);color:var(--txt);
  border:1px solid var(--line);font-size:.92rem;margin:10px 0;
}
button{
  width:100%;padding:12px;border:none;border-radius:10px;font-weight:800;font-size:.9rem;cursor:pointer;
  background:linear-gradient(135deg,#00a2c9,#0077b6);color:#fff;letter-spacing:.6px;transition:all .2s;
}
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

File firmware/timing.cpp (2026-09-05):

/*
 * timing.cpp - Input capture e calcolo timing iniettori/candele (FASE 2)
 *
 * Misura i PWM di uscita della Speeduino (4 iniettori + 4 candele + ventola).
 * Segnali LOW-SIDE attivi bassi: dopo il CD4050BE non-inverting il livello rimane
 * LOW = attivo.
 *
 * - Le ISR (IRAM_ATTR, accesso direttamente a GPIO.in per evitare i problemi di
 *   digitalRead/digitalWrite in ISR su ESP32 Arduino Core v3.3.5) salvano SOLO
 *   timestamp (bassissima latenza, nessun blocco del loop di simulazione).
 * - Il calcolo dei valori finali (ms, gradi, Hz, duty) avviene in timingUpdate()
 *   chiamato dal loop() a bassa priorita'.
 *
 * Riferimento per l'anticipo candela: l'ESP32 e' il "master" della ruota fonica,
 * quindi conosce l'istante di ogni fronte Crank (lastCrankEdgeUs, scritto dalla
 * ISR del timer). L'anticipo = (delta rispetto al fronte Crank) +/- swap.
 */

#include "timing.h"
#include "globals.h"
#include "soc/gpio_struct.h"
#include "soc/gpio_reg.h"

extern wheels Wheels[];

// Lati dei pin reali (mappatura FASE 2 verificata)
static const uint8_t injPin[4] = { PIN_INJ1, PIN_INJ2, PIN_INJ3, PIN_INJ4 };
static const uint8_t ignPin[4] = { PIN_IGN1, PIN_IGN2, PIN_IGN3, PIN_IGN4 };

// Timestamp grezzi scritti SOLO dalle ISR (volatile)
struct injRaw {
  volatile uint32_t lastStartUs;   // ultimo fronte di discesa (inizio apertura)
  volatile uint32_t lastRiseUs;    // ultimo fronte di salita (fine apertura)
  volatile uint32_t periodUs;      // periodo tra due iniezioni
  volatile uint32_t onTimeUs;      // tempo apertura (on-time)
};
static injRaw injRawData[4];

struct ignRaw {
  volatile uint32_t sparkStartUs;  // inizio impulso candela (fronte discesa)
  volatile uint32_t sparkEndUs;    // fine impulso candela (fronte salita)
  volatile uint32_t lastRsUs;      // ultimo fronte salita (per il periodo)
  volatile uint32_t dwellUs;       // durata impulso candela (dwell)
  volatile uint32_t periodUs;      // periodo tra due candele
};
static ignRaw ignRawData[4];

// Fronte di riferimento Crank (scritto dalla ISR del timer nel .ino)
volatile uint32_t lastCrankEdgeUs = 0;

// Inizio del pattern (edge_counter==0): riferimento angolare del ciclo
volatile uint32_t revStartUs = 0;

// --- ISR INIETTORI (attivo basso: DISCESA = apertura, SALITA = chiusura) ---
#define MAKE_INJ_ISR(i)                                                                \
void IRAM_ATTR injISR##i() {                                                           \
  uint32_t now = micros();                                                             \
  if (GPIO.in & (1ULL << injPin[i])) {  /* SALITA: fine apertura */                   \
    injRawData[i].onTimeUs = now - injRawData[i].lastStartUs;                          \
    injRawData[i].periodUs = now - injRawData[i].lastRiseUs;                           \
    injRawData[i].lastRiseUs = now;                                                    \
  } else {                          /* DISCESA: inizio apertura */                     \
    injRawData[i].lastStartUs = now;                                                   \
  }                                                                                    \
}

MAKE_INJ_ISR(0)
MAKE_INJ_ISR(1)
MAKE_INJ_ISR(2)
MAKE_INJ_ISR(3)

// --- ISR CANDELE (attivo basso: DISCESA = inizio spark, SALITA = fine spark) ---
#define MAKE_IGN_ISR(i)                                                                \
void IRAM_ATTR ignISR##i() {                                                           \
  uint32_t now = micros();                                                             \
  if (GPIO.in & (1ULL << ignPin[i])) {  /* SALITA: fine spark */                      \
    ignRawData[i].dwellUs = now - ignRawData[i].sparkStartUs;                          \
    ignRawData[i].periodUs = now - ignRawData[i].lastRsUs;                             \
    ignRawData[i].lastRsUs = now;                                                      \
    ignRawData[i].sparkEndUs = now;                                                    \
  } else {                          /* DISCESA: inizio spark */                        \
    ignRawData[i].sparkStartUs = now;                                                  \
  }                                                                                    \
}

MAKE_IGN_ISR(0)
MAKE_IGN_ISR(1)
MAKE_IGN_ISR(2)
MAKE_IGN_ISR(3)

// --- SETUP: pin in ingresso con pull-up e attachInterrupt su CHANGE ---
void timingSetup() {
  // Configurazione pin (tutti con pull-up interno)
  pinMode(PIN_INJ1, INPUT_PULLUP);
  pinMode(PIN_INJ2, INPUT_PULLUP);
  pinMode(PIN_INJ3, INPUT_PULLUP);
  pinMode(PIN_INJ4, INPUT_PULLUP);
  pinMode(PIN_IGN1, INPUT_PULLUP);
  pinMode(PIN_IGN2, INPUT_PULLUP);
  pinMode(PIN_IGN3, INPUT_PULLUP);
  pinMode(PIN_IGN4, INPUT_PULLUP);

  // Interrupt su ogni fronte (CHANGE)
  attachInterrupt(digitalPinToInterrupt(PIN_INJ1), injISR0, CHANGE);
  attachInterrupt(digitalPinToInterrupt(PIN_INJ2), injISR1, CHANGE);
  attachInterrupt(digitalPinToInterrupt(PIN_INJ3), injISR2, CHANGE);
  attachInterrupt(digitalPinToInterrupt(PIN_INJ4), injISR3, CHANGE);
  attachInterrupt(digitalPinToInterrupt(PIN_IGN1), ignISR0, CHANGE);
  attachInterrupt(digitalPinToInterrupt(PIN_IGN2), ignISR1, CHANGE);
  attachInterrupt(digitalPinToInterrupt(PIN_IGN3), ignISR2, CHANGE);
  attachInterrupt(digitalPinToInterrupt(PIN_IGN4), ignISR3, CHANGE);

  // Azzera le strutture pubbliche
  for (uint8_t i = 0; i < 4; i++) {
    injectors[i].active      = false;
    injectors[i].onTimeMs    = 0.0f;
    injectors[i].frequencyHz = 0.0f;
    injectors[i].dutyPct     = 0;

    ignitions[i].active      = false;
    ignitions[i].dwellMs     = 0.0f;
    ignitions[i].advanceDeg  = 0;
  }
}

// --- AUTOTEST: generatore PWM su GPIO32/33 per verificare la catena di acquisizione.
//   GPIO32 -> INJ1 (50 Hz, on-time 4.0 ms -> duty 20%)
//   GPIO33 -> IGN1 (100 Hz, dwell 2.0 ms)
//   I segnali Speeduino sono attivi-bassi: il calcolo quindi usa il tempo LOW.
//   ledcWrite = parte HIGH; usiamo 80% HIGH -> 20% LOW.
void timingTest(bool on) {
  if (on) {
    ledcAttach(32, 50, 12);   ledcWrite(32, 3276);  // INJ1: periodo 20ms, LOW 4ms
    ledcAttach(33, 100, 12);  ledcWrite(33, 3276);  // IGN1: periodo 10ms, LOW 2ms
  } else {
    ledcDetach(32);
    ledcDetach(33);
  }
}
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

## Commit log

2026-09-05 Initial commit: Engine Simulator 2.0 - firmware ESP32, wiring, KiCad hardware
    [Engine Simulator 2.0.kicad_pcb, Engine Simulator 2.0.kicad_sch]
2026-09-05 Fase 2/3: timing iniettori e candele su ESP32 + dashboard WiFi
    - timing.cpp/h: input capture ISR su GPIO ad alta priorita, calcolo
    fase/frequenza/duty iniettori e dwell/anticipo candele
    - web.cpp/h: dashboard web (RPM gauge, TPS/MAP/CLT, timing tabelle),
    setup pagina con selezione ruota fonica persistente su NVS
    - Comando web /api/start: avvio/stop motore (toggle, specchio pulsante GPIO)
    - Fix dashboard: elemento rpm-val mancante, lunghezza arco, RPM unita piene
    - Fix salvataggio ruota: endpoint GET, Cache-Control no-store, rimozione
    array JS names fragile (apice in 'half moon')
    - Fix TPS: analogSetPinAttenuation ADC_11db su GPIO34
    - Fix compile core 3.3.11: include soc/gpio_*.h, fork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
    [Engine_Simulator_2.0.ino, Engine_Simulator_2_0.ino, timing.cpp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]
2026-09-05 Timing: autotest segnali + fix anticipo candela riferito al ciclo
    - timingTest(): genera PWM noti su GPIO32/33 (jumper verso INJ1/IGN1)
    per validare ISR->calcolo->dashboard senza Speeduino
    - Endpoint /api/test (GET) con pulsante dedicato in dashboard
    - Fix anticipo: riferimento lastCrankEdgeUs (singolo dente, rumoroso)
    sostituito con revStartUs (inizio pattern, edge_counter==0);
    range normalizzato a wheel_degrees con wrap-aware signed diff
    - Verificato: INJ1 = 4.0ms/50Hz/20%, IGN1 = 2.0ms dwell, anticipo <= 360 su 60-2
    [Engine_Simulator_2.0.ino, Engine_Simulator_2_0.ino, timing.cpp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]
2026-09-05 Hardware: correzioni schema KiCad - fixes iniettori/candele
    [Engine Simulator 2.0.kicad_sch]
2026-09-06 Update README to reflect correct ESP32 model
2026-09-06 Clarify MAP sensor usage and potentiometer roles
    Updated information regarding the MAP sensor and clarified the functionality of IAT and O2 potentiometers.
2026-09-18 Routing completo board + piano GND con thermal relief su B.Cu
    [Engine Simulator 2.0.kicad_pcb, Engine Simulator 2.0.kicad_sch]
2026-09-18 Aumentata la pista di alimentazione a ESP32
    [Engine Simulator 2.0.kicad_pcb]
2026-09-18 modificata grafica
    [Engine Simulator 2.0.kicad_pcb]
2026-09-19 Refill piano GND (fix 5 violazioni clearance) + report DRC e README aggiornati
    [Engine Simulator 2.0.kicad_pcb]
2026-09-19 hw: generati Gerber+drill (FAB) e zip gerbers; README: sezione fab
    [Engine Simulator 2.0-B_Cu.gbr, Engine Simulator 2.0-B_Mask.gbr, Engine Simulator 2.0-B_Paste.gbr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]
2026-09-21 chore(git): add .gitattributes per normalizzazione LF file KiCad + fix .gitignore (lock pcb)
2026-09-21 hw: sostituito L7805 con RECOM R-78E5.0-1.0 (switching drop-in) in schema, PCB e BOM + rigenerati Gerber
    [Engine Simulator 2.0-B_Cu.gbr, Engine Simulator 2.0-B_Mask.gbr, Engine Simulator 2.0-B_Paste.gbr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]
2026-09-21 hw: rigenerato zip FAB con gerber+drill aggiornati (RECOM R-78E5.0-1.0)
2026-09-21 docs: aggiornato README e pinout (rimossi LED, CD4050, no sync due PC) + UNtrack sessions private
2026-09-21 docs: aggiunta BOM.md (estratta dal netlist) + allineate quantita' README allo schema
2026-09-25 docs: rimosso riferimento stale ai LED di stato dagli header .ino
2026-09-25 hw: config export BOM KiCad (filename + campi) e BOM.csv generata
    [Engine Simulator 2.0_BOM.csv]
2026-10-06 hw: autorouting con FreeRouting (zona GND solo B.Cu), allargamento piste min 0.2mm, rigenerazione Gerber + drill + FAB zip
    [Engine Simulator 2.0-B_Courtyard.gbr, Engine Simulator 2.0-B_Cu.gbl, Engine Simulator 2.0-B_Fab.gbr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]
2026-10-07 docs: rewrite ESP32U pin assignment in clean engineering format
2026-10-08 docs: add PCB 3D render image to README
2026-10-19 feat: add startup Sync Mode (passive/active) and consolidate firmware tree
    Firmware:
    - Add selectable startup Sync Mode (Passive = autonomous, Active = ECU-driven)
    persisted in NVS and exposed on /setup and /api/data.
    - Detect real firing via injector/ignition ISR timestamps (hasRecentFiring).
    - Fix Crank/Cam output by using direct GPIO registers inside the timer ISR.
    - Fix corrupted globals.h/web.cpp (UTF-8 BOM) and missing timing.h prototypes.
    Repo:
    - Publish from the single Engine_Simulator_2_0/ sketch folder; remove the
    historical firmware/ duplicate.
    Docs:
    - Add English versions of all documentation (README, pinout, Dupont,
    working version, implementation plan, BOM) and keep the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
